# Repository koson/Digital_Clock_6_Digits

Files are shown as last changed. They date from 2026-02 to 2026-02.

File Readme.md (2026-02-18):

# Digital Clock 6 Digits

## คำแนะนำ
สร้างนาฬิกา Digital 6 Digit โดยใช้อุปกรณ์ที่เรียนในวิชา เพื่อแสดงเวลาในรูปแบบ HH:MM:SS โดยใช้หลักการทำงานของวงจร Digital Logic และ Counter 

โครงงานนี้ใช้วิธีการเดินสายด้วย Wire wrapping เพื่อลดขั้นตอนในการทำ PCB และเป็นการฝึกให้นักศึกษาได้บัดกรีวงจรที่มีความซับซ้อนในระดับที่เหมาะสม

รูปตัวอย่างของบอร์ดทั้งหมด ไม่ได้เป็นข้อบังคับให้นักศึกษาต้องทำให้เหมือน อีกทั้งนักศึกษาสามารถเพิ่มเติมฟังก์ชันที่ดีกว่าต้นฉบับได้ แต่ไม่ควรน้อยกว่าเป็นอันขาด

ไฟล์ทั้งหมดที่ใช้อธิบายการทำงานและสร้างโครงงาน อยู่ในโฟลเดอร์ Documents

#### ถ้ามีข้อสงสัยหรือต้องการคำอธิบายเพิ่ม ให้เปิด issue มาได้เลยนะครับ

## 🆘 ขี้เกียจอ่านยาว ๆ  เชิญทางนี้เลยครับ [🛝](./Documents/Short-Docs.md) 

## 🆘 หรือไม่อยากอ่านเลย อยากดูคลิปอย่างเดียว  ก็เชิญทางนี้เลยครับ [🎞️](./Documents/Video-Links.md) 

---

## 📐 สถาปัตยกรรม Hardware แบบ MVC (Model-View-Controller)

<p align="center">
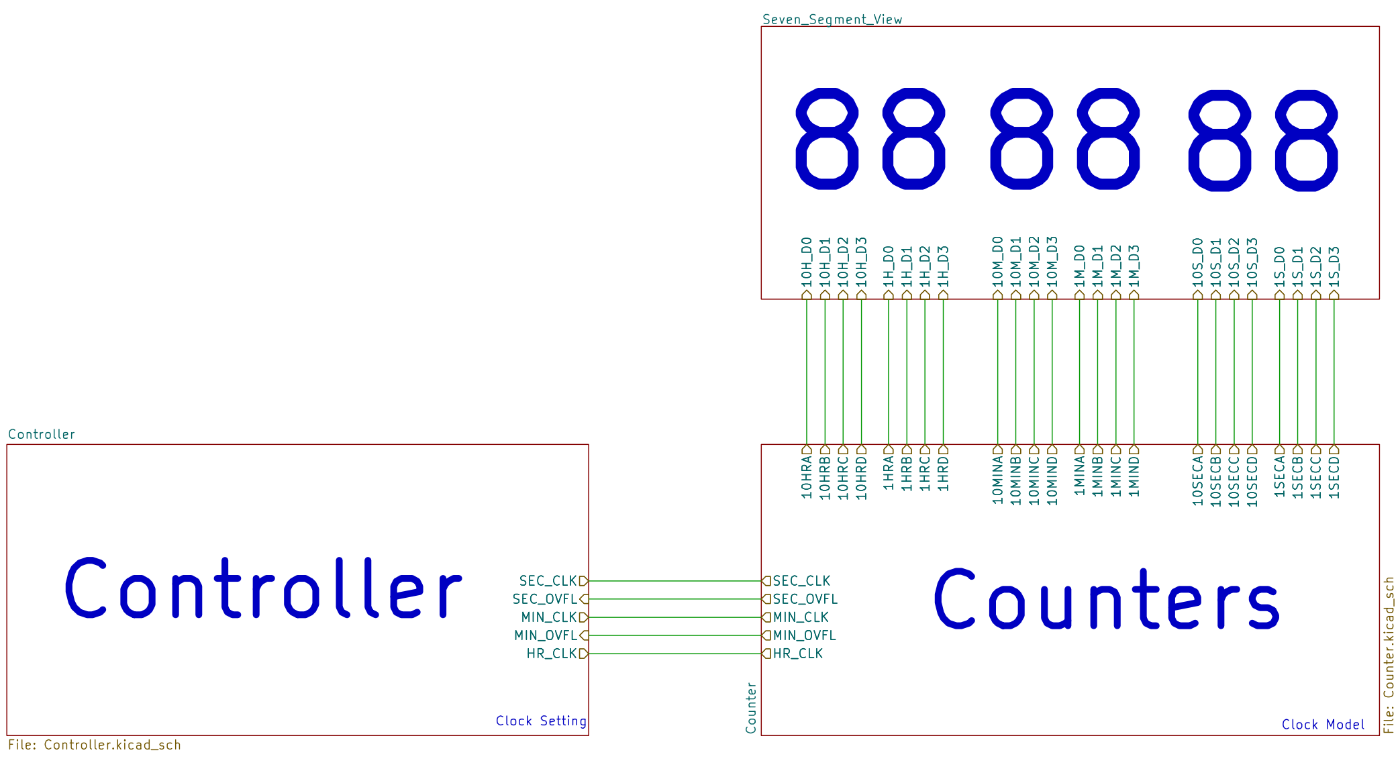
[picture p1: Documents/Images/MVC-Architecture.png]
MVC Architecture

</p>
โปรเจคนี้ออกแบบโดยแบ่งส่วนการทำงานออกเป็น 3 ส่วนหลักตามแนวคิด MVC:

### 🎮 **Controller** - ส่วนควบคุมและสร้างสัญญาณ Clock
- **หน้าที่:** สร้างสัญญาณนาฬิกา (Clock Signal) ที่ความถี่ 1 Hz (1 วินาที/รอบ) พร้อมทั้งสวิตช์กดเพื่อการตั้งเวลา
- **อุปกรณ์หลักส่วนกำเนิดสัญญาณนาฬิกา:** 
  - NE555 Timer ในโหมด Astable เพื่อสร้าง Clock pulse
  - LED และตัวต้านทาน  
- **ผลลัพธ์:** สัญญาณ Clock ที่มีความแม่นยำสำหรับนับเวลา สามารถสังเกตุการทำงานจากการกระพริบของ LED

- **อุปกรณ์หลักส่วนตั้งเวลาสำหรับนาฬิกา:** 
  - สวิตช์กด push button ชนิด กดติดปล่อยดับ
  - ตัวต้านทาน  Pull-up หรือ Pull Down
  - ตัวเก็บประจุ debouncing
  - SN7414 Schmitt Trigger สำหรับปรับสัญญาณให้เสถียร
  - SN7474 D Flip-Flop สำหรับสลับโหมด (RUN/SETTIME)
  - SN74LS157 Multiplexer สำหรับเลือกเส้นทางสัญญาณสำหรับโหมด  RUN และ SETTIME
- **ผลลัพธ์:** การกดปุ่มแต่ละครั้ง ไม่มี bounce และสามารถเปลี่ยนโหมด (RUN/SETTIME) และเพิ่มค่าในหลัก HH:MM:SS ครั้งละ 1 ได้ตามต้องการ 

### 📊 **Model** - ส่วนประมวลผลและนับเวลา (Counters)
- **หน้าที่:** นับและจัดเก็บค่าเวลา (ชั่วโมง นาที วินาที) ในรูปแบบ BCD
- **อุปกรณ์หลัก:**
  - SN74LS390 Decade Counter (นับเลข 0-9 และ 0-5)
- **โครงสร้างการนับ:**
  - วินาทีหลักหน่วย: 0-9 (ใช้ Counter mod-10)
  - วินาทีหลักสิบ: 0-5 (ใช้ Counter mod-6)
  - นาทีหลักหน่วย: 0-9 (ใช้ Counter mod-10)
  - นาทีหลักสิบ: 0-5 (ใช้ Counter mod-6)
  - ชั่วโมงหลักหน่วย: 0-9 (ใช้ Counter mod-10)
  - ชั่วโมงหลักสิบ: 0-2 (ใช้ Counter mod-3 สำหรับรูปแบบ 24 ชั่วโมง)

### 🖥️ **View** - ส่วนแสดงผล (7 Segments)
- **หน้าที่:** แสดงค่าเวลาออกทาง 7-Segment Display
- **อุปกรณ์หลัก:**
  - CD4543 BCD-to-7-Segment Decoder (6 ตัว สำหรับแต่ละหลัก)
  - 7-Segment Display Common Cathode (6 หลัก)
- **การทำงาน:** รับค่า BCD จาก Model แปลงเป็นรหัส 7-Segment เพื่อแสดงผลตัวเลข 0-9

---

## 🔧 การทำงานของแต่ละส่วนในโปรเจค

### 1. ส่วน Clock Generator (NE555)
- สร้างสัญญาณสี่เหลี่ยมความถี่ ~1 Hz
- ใช้สูตรคำนวณ: $f = \frac{1.44}{(R_1 + 2R_2) \times C}$
- ค่าที่ใช้: R1 = 1kΩ, R2 = 6.8kΩ, C = 100µF
- ความถี่ที่ได้: 0.986 Hz (ความคลาดเคลื่อน 1.4%)

### 2. ส่วน Counter (SN74LS390)
**วินาที:**
- Counter ตัวที่ 1: นับหลักหน่วย 0→9 (mod-10)
- Counter ตัวที่ 2: นับหลักสิบ 0→5 (mod-6)
- เมื่อครบ 59 วินาที Reset และส่งสัญญาณ Carry ไปยังส่วนนาที

**นาที:**
- Counter ตัวที่ 3: นับหลักหน่วย 0→9 (mod-10)
- Counter ตัวที่ 4: นับหลักสิบ 0→5 (mod-6)
- เมื่อครบ 59 นาที Reset และส่งสัญญาณ Carry ไปยังส่วนชั่วโมง

**ชั่วโมง:**
- Counter ตัวที่ 5: นับหลักหน่วย 0→9 (mod-10)
- Counter ตัวที่ 6: นับหลักสิบ 0→2 (mod-3)
- เมื่อครบ 23:59:59 Reset กลับเป็น 00:00:00

### 3. ส่วน Display (CD4543 + 7-Segment)
- รับสัญญาณ BCD 4 บิตจาก Counter แต่ละหลัก
- CD4543 ทำหน้าที่แปลง BCD เป็นสัญญาณควบคุม 7-Segment (a-g)
- แสดงผลตัวเลข 0-9 บน 7-Segment Display

### 4. ส่วน Time Setting
- Switch สำหรับหยุดนับและปรับเวลา
- Push Button สำหรับตั้งค่าชั่วโมง/นาที/วินาที

---

## 📁 คำอธิบายไฟล์ในโปรเจค

### 📄 Markdown Documents
- **`Readme.md`** - เอกสารหลักของโปรเจค อธิบายภาพรวมและวิธีการทำงาน
- **[`Bill-of-materials.md`](Documents/Bill-of-materials.md)** - รายการอุปกรณ์ที่ใช้ในโปรเจค
- **[`Construction-Process.md`](Construction-Process-Display.md)** - ขั้นตอนการประกอบวงจรตามลำดับ
- **[`Datasheets.md`](Documents/Datasheets.md)** - รายละเอียด Datasheet ของ IC ที่ใช้ในวงจร
- **[`Kicad-Setup.md`](Documents/Kicad-Setup.md)** - คู่มือการตั้งค่าและใช้งาน KiCad
- **[`NE555_Clock.md`](NE555-Clock-Generator.md)** - การคำนวณและออกแบบวงจร NE555

### 🔌 Circuit Files (โฟลเดอร์ Circuit/)
- **[`Digital_Clock_6_Digits.kicad_pro`](Circuit/Digital_Clock_6_Digits.kicad_pro)** - ไฟล์โปรเจค KiCad หลัก
- **[`Digital_Clock_6_Digits.kicad_sch`](Circuit/Digital_Clock_6_Digits.kicad_sch)** - Schematic หลักที่เชื่อมโยงส่วนย่อย
- **[`Controller.kicad_sch`](Circuit/Controller.kicad_sch)** - วงจร NE555 Clock Generator
- **[`Counter.kicad_sch`](Circuit/Counter.kicad_sch)** - วงจร Counter ทุกหลัก (วินาที นาที ชั่วโมง)
- **[`7Seg_6Digits.kicad_sch`](Circuit/7Seg_6Digits.kicad_sch)** - วงจร Decoder และ Display 6 หลัก
- **[`Seven_Segment_View.kicad_sch`](Circuit/Seven_Segment_View.kicad_sch)** - มุมมองการเชื่อมต่อ 7-Segment
- **[`Digital_Clock_6_Digits.kicad_pcb`](Circuit/Digital_Clock_6_Digits.kicad_pcb)** - ไฟล์ออกแบบ PCB
- **[`Library.kicad_sym`](Circuit/Library.kicad_sym)** - ไลบรารีสัญลักษณ์ที่ใช้ในโปรเจค
- **[`Digital_Clock_6_Digits.csv`](Circuit/Digital_Clock_6_Digits.csv)** - Bill of Materials จาก KiCad

---

## 🛠️ ลำดับขั้นตอนการทำโปรเจค

``` mermaid
%%{init: {'theme':'base', 'flowchart': {'padding': 20, 'nodeSpacing': 50, 'rankSpacing': 50}, 'themeVariables': {'fontSize':'13px', 'fontFamily':'Arial'}}}%%
flowchart TD
    Phase1["Study documentation"] --> Phase2["Study schematic in Kicad"]
    Phase2 --> Phase3["Acquire components"]   

    subgraph "building circuit"
        direction TB
        Phase4
        Phase5
        Phase6
    end
    Phase3 --> Phase4["Build Display circuit"]
    Phase4 --> Phase5["Build Counter circuit"]
    Phase5 --> Phase6["Build Controller circuit"]
    Phase6 --> Phase7["Test and Debug"]
    Phase7 --> Phase7-1{"Does it work?"}
    Phase7-1 -->|Yes| Phase8["Document and Publish"]
    Phase7-1 -->|No| Phase3["Acquire components"]
```

### Phase 1: ศึกษาเอกสารต่างๆ (เริ่มจากไฟล์ Readme.md)
- [ ] **ศึกษา Datasheet** ของ IC แต่ละตัวให้เข้าใจการทำงาน โดยเฉพาะ:
	- [ ] CD4543 (BCD-to-7-Segment Decoder)
	- [ ] SN74LS390 (Decade Counter)
	- [ ] NE555 (Timer)
	- [ ] SN74LS157 (Multiplexer)

- [ ] **ศึกษาวงจรย่อย** แต่ละส่วนที่อาจารย์ให้ไว้:
	- [ ] วงจร Clock Generator (NE555)
	- [ ] วงจร Counter (SN74LS390) สำหรับ วินาที นาที ชั่วโมง
    - [ ] วงจร Display (CD4543 + 7-Segment)

- [ ]  **คำนวณค่าอุปกรณ์:** ถ้าอุปกรณ์ที่หามาได้ไม่ตรงกับค่าในวงจร 
	- [ ]  คำนวณ R และ C สำหรับ NE555 ให้ได้ความถี่ 1 Hz
	- [ ]  ตรวจสอบ Duty Cycle ให้อยู่ในช่วง 40-60%

### Phase 2: ศึกษาวงจรใน KiCad (ต้องลงโปรแกรม KiCad)
- [ ] **สร้าง Schematic แยกตามส่วน:**
    - [ ] `Controller.kicad_sch` - วงจร NE555
    - [ ] `Counter.kicad_sch` - วงจรนับเวลา
    - [ ] `7Seg_6Digits.kicad_sch` - วงจรแสดงผล
    - [ ] `Digital_Clock_6_Digits.kicad_sch` - เชื่อมโยงทุกส่วนเข้าด้วยกัน

- [ ] **ตรวจสอบความถูกต้อง:**
    - [ ] ตรวจสอบการเชื่อมต่อระหว่างส่วน
    - [ ] ตรวจสอบ Power Supply (VCC, GND)
    - [ ] ใช้มัลติมิเตอร์ตรวจสอบข้อผิดพลาด

### Phase 3: จัดหาอุปกรณ์ตามรายการ
- [ ] **จัดทำรายการอุปกรณ์ (BOM - Bill of Materials):**
    - [ ] IC ทั้งหมดตาม Schematic (CD4543, SN74LS390, NE555, SN74LS157, SN7414, SN7474)
    - [ ] 7-Segment Display Common Cathode 6 หลัก ควรใส่ Socket หรือ connector ตามคำแนะนำในการประกอบวงจร
    - [ ] ตัวต้านทาน (Resistor) ค่าต่างๆ ตามที่คำนวณไว้ในวงจร
    - [ ] ตัวเก็บประจุ (Capacitor) สำหรับวงจร NE555 และ Decoupling
    - [ ] แผ่นวงจรเอนกประสงค์ (Universal PCB) ขนาดที่เหมาะสม
    - [ ] IC Socket สำหรับ IC ทุกตัว (แนะนำให้ใช้เพื่อความสะดวกในการเปลี่ยน IC)
    - [ ] สาย Wire Wrap หรือสายเดินสายแบบอ่อน (Jumper Wire)
    - [ ] Push Button Switch สำหรับตั้งค่าเวลา
    - [ ] LED สำหรับแสดงสถานะ Clock
    - [ ] แหล่งจ่ายไฟ 5V (Adapter หรือ Battery)

- [ ] **ตรวจสอบอุปกรณ์:**
    - [ ] ตรวจสอบความถูกต้องของ IC ทุกตัวด้วย Datasheet
    - [ ] ทดสอบค่าตัวต้านทานและตัวเก็บประจุด้วย Multimeter
    - [ ] ตรวจสอบ 7-Segment Display ว่าเป็น Common Cathode
    - [ ] เตรียมอุปกรณ์สำรอง (IC, ตัวต้านทาน, สาย) กรณีชำรุด

### Phase 4: ประกอบส่วน Display
- [ ] **เตรียมอุปกรณ์สำหรับส่วน Display:**
    - [ ] IC Socket สำหรับ CD4543 (6 ตัว)
    - [ ] CD4543 BCD-to-7-Segment Decoder (6 ตัว)
    - [ ] 7-Segment Display Common Cathode (6 หลัก)
    - [ ] ตัวต้านทาน Current Limiting สำหรับ LED แต่ละ Segment
    - [ ] แผ่นวงจรเอนกประสงค์ขนาดพอเหมาะ

- [ ] **วางตำแหน่ง Component:**
    - [ ] วาง 7-Segment Display ให้เรียงตามลำดับ (HH:MM:SS)
    - [ ] วาง IC Socket สำหรับ CD4543 ไว้ใกล้กับ 7-Segment แต่ละหลัก
    - [ ] วางตำแหน่งให้พิจารณาเส้นทางการเดินสายไปยัง Counter (ส่วนถัดไป)
    - [ ] สามารถวางตามตัวอย่างในรูปชิ้นงานที่สำเร็จแล้วได้ 

- [ ] **บัดกรี Component:**
    - [ ] บัดกรี 7-Segment Display ทั้ง 6 หลัก ตรวจสอบให้แน่ใจว่าหลักตรง
    - [ ] บัดกรี IC Socket สำหรับ CD4543 ทั้ง 6 ตัว ตรวจสอบทิศทางขา 1
    - [ ] บัดกรีตัวต้านทาน Current Limiting สำหรับแต่ละ Segment

- [ ] **เดินสายด้วย Wire Wrap:**
    - [ ] เชื่อมต่อสาย VCC และ GND ให้ทุก IC (ควรเดินสายเป็นแนว Bus)
    - [ ] เชื่อมต่อสาย Output a-g จาก CD4543 ไปยัง 7-Segment แต่ละหลัก
    - [ ] เชื่อมต่อขา Common Cathode ของ 7-Segment ทั้งหมดไปยัง GND
    - [ ] เตรียมจุดต่อสำหรับสาย Input BCD (4 บิต) จากส่วน Counter

- [ ] **ทดสอบส่วน Display:**
    - [ ] **ยังไม่ต้องใส่ CD4543 ลงใน IC Socket**
    - [ ] จ่ายไฟ 5V ตรวจสอบแรงดันที่ขาไฟเลี้ยงและ ground ของ IC ทุกตัว
    - [ ] ถ้าวัดไฟแล้วไม่มีอะไรผิดพลาด ให้ปลดไฟเลี้ยงออกแล้วเสียบ IC ลงไปใน socket โดยทำจากหลักวินาทีเพียงตัวเดียวก่อน
    - [ ] จ่ายไฟเข้าวงจร IC ต้องไม่ร้อนกว่าปกติ วัดแรงดันไฟเลี้ยงควรได้เท่ากับตอนที่ยังไม่เสียบ IC 
    - [ ] ทดสอบการแสดงผลด้วยการจ่ายสัญญาณ BCD แบบ Manual (ใช้สวิตช์หรือสาย Jumper)
    - [ ] ตรวจสอบว่าแต่ละหลักสามารถแสดงตัวเลข 0-9 ได้ถูกต้อง
    - [ ] บันทึกปัญหาที่พบ (ถ้ามี) เช่น Segment ที่ไม่ติด

### Phase 5: ประกอบส่วน Counter
- [ ] **เตรียมอุปกรณ์สำหรับส่วน Counter:**
    - [ ] IC Socket สำหรับ SN74LS390 (3 ตัว สำหรับ วินาที นาที ชั่วโมง)
    - [ ] SN74LS390 Dual Decade Counter (3 ตัว)
    - [ ] ตัวเก็บประจุ Decoupling 0.1µF สำหรับแต่ละ IC
    - [ ] แผ่นวงจรเอนกประสงค์ขนาดพอเหมาะ (หรือใช้แผ่นเดียวกับ Display)

- [ ] **วางตำแหน่ง Component:**
    - [ ] วาง IC Socket สำหรับ Counter ตามลำดับ: วินาที → นาที → ชั่วโมง
    - [ ] วางให้สะดวกต่อการเชื่อมต่อกับส่วน Display และ Controller
    - [ ] คำนึงถึงการเดินสายระหว่าง Counter แต่ละหลัก (Cascade)
    - [ ] สามารถวางตำแหน่งตามในรูปวงจรต้นแบบได้

- [ ] **บัดกรี Component:**
    - [ ] บัดกรี IC Socket สำหรับ SN74LS390 ทั้ง 3 ตัว
    - [ ] บัดกรีตัวเก็บประจุ Decoupling ไว้ใกล้ขา VCC และ GND ของแต่ละ IC
    - [ ] บัดกรี IC Logic Gate เพิ่มเติม (ถ้ามี) สำหรับวงจร Reset

- [ ] **เดินสายด้วย Wire Wrap:**
    - [ ] เชื่อมต่อสาย VCC และ GND ให้ทุก IC
    - [ ] **วงจรวินาที:** บัดกรีวงจรตามที่แสดงใน Kicad
        - [ ] เชื่อมต่อ Clock Input สำหรับนับวินาทีหลักหน่วย (0-9)
        - [ ] เชื่อมต่อ Carry Output ไปยังหลักสิบ (0-5)
        - [ ] ต่อขา Output BCD (4 บิต) ของทั้ง 2 หลักไปยังส่วน Display
        - [ ] ต่อวงจร Reset เมื่อครบ 59 → 00
    - [ ] **วงจรนาที:** บัดกรีวงจรตามที่แสดงใน Kicad
        - [ ] รับ Clock Input จาก Carry ของวินาทีหลักสิบ
        - [ ] เชื่อมต่อ Carry Output ไปยังหลักสิบ (0-5)
        - [ ] ต่อขา Output BCD ไปยังส่วน Display
        - [ ] ต่อวงจร Reset เมื่อครบ 59 → 00
    - [ ] **วงจรชั่วโมง:** บัดกรีวงจรตามที่แสดงใน Kicad
        - [ ] รับ Clock Input จาก Carry ของนาทีหลักสิบ
        - [ ] เชื่อมต่อหลักหน่วย (0-9) และหลักสิบ (0-2)
        - [ ] ต่อขา Output BCD ไปยังส่วน Display
        - [ ] ต่อวงจร Reset เมื่อครบ 23 → 00 (รูปแบบ 24 ชั่วโมง)

- [ ] **เชื่อมต่อส่วน Display เข้ากับ Connector ทั้ง 6 ตัว:**
    - [ ] ต่อสาย BCD Output จาก Counter แต่ละหลักไปยัง Input ของ CD4543
    - [ ] ตรวจสอบความถูกต้องของการต่อสาย (bit 0-3)

- [ ] **ทดสอบส่วน Counter:**
    - [ ] ใส่ IC SN74LS390 ลงใน IC Socket ทุกตัว
    - [ ] จ่ายไฟ 5V และตรวจสอบแรงดันที่ IC ทุกตัว
    - [ ] จ่ายสัญญาณ Clock แบบ Manual (กดปุ่มหรือใช้ Switch)
    - [ ] ตรวจสอบการนับของวินาที: 00 → 01 → ... → 09 → 10 → ... → 59 → 00
    - [ ] ตรวจสอบ Carry Signal ส่งต่อไปยังนาทีเมื่อวินาทีครบ 59
    - [ ] ตรวจสอบการนับของนาทีและชั่วโมงแบบเดียวกัน
    - [ ] ตรวจสอบว่าเมื่อครบ 23:59:59 แล้ว จะ Reset เป็น 00:00:00

### Phase 6: ประกอบส่วน Controller (Clock Generator และ Time Setting)
- [ ] **เตรียมอุปกรณ์สำหรับส่วน Controller:**
    - [ ] IC Socket สำหรับ NE555, SN7414, SN7474, SN74LS157
    - [ ] NE555 Timer IC
    - [ ] SN7414 Schmitt Trigger (สำหรับปรับสัญญาณ)
    - [ ] SN7474 D Flip-Flop (สำหรับสลับโหมด RUN/SETTIME)
    - [ ] SN74LS157 Multiplexer (สำหรับเลือกสัญญาณ Clock)
    - [ ] ตัวต้านทาน 1kΩ, 6.8kΩ (หรือค่าที่คำนวณได้)
    - [ ] ตัวเก็บประจุ 100µF (หรือค่าที่คำนวณได้)
    - [ ] Push Button Switch (สำหรับ Mode Switch, Hour, Minute, Second)
    - [ ] LED สำหรับแสดงสถานะ Clock และโหมด
    - [ ] ตัวต้านทาน Pull-up/Pull-down สำหรับปุ่ม
    - [ ] ตัวเก็บประจุ Debouncing สำหรับปุ่มกด
    - [ ] แผ่นวงจรเอนกประสงค์ขนาดพอเหมาะ

- [ ] **ส่วน Clock Generator (NE555):**
    - [ ] บัดกรี IC Socket สำหรับ NE555
    - [ ] บัดกรีตัวต้านทาน R1 (1kΩ) และ R2 (6.8kΩ)
    - [ ] บัดกรีตัวเก็บประจุ C (100µF)
    - [ ] บัดกรี LED และตัวต้านทาน Current Limiting
    - [ ] เดินสายตาม Schematic ของ NE555 Astable Mode
    - [ ] เชื่อม Output ของ NE555 ไปยัง SN7414 (Schmitt Trigger)

- [ ] **ส่วน Time Setting:**
    - [ ] บัดกรี Push Button ทั้งหมด (Mode, Hour, Minute, Second)
    - [ ] บัดกรีตัวต้านทาน Pull-up/Pull-down สำหรับปุ่มแต่ละตัว
    - [ ] บัดกรีตัวเก็บประจุ Debouncing ควบคู่กับปุ่ม
    - [ ] บัดกรี IC Socket สำหรับ SN7414, SN7474, SN74LS157
    - [ ] เดินสาย Output จากปุ่มผ่าน SN7414 เพื่อปรับสัญญาณให้เสถียร
    - [ ] เดินสายจาก SN7474 เพื่อสลับระหว่างโหมด RUN และ SETTIME
    - [ ] เดินสายจาก SN74LS157 เพื่อเลือก Clock Source:
        - [ ] โหมด RUN: ใช้สัญญาณจาก NE555 (1 Hz)
        - [ ] โหมด SETTIME: ใช้สัญญาณจากปุ่มกด (Manual Clock)

- [ ] **เชื่อมต่อกับส่วน Counter:**
    - [ ] ต่อ Output จาก Multiplexer (SN74LS157) ไปยัง Clock Input ของ Counter
    - [ ] ต่อสัญญาณจากปุ่ม Hour, Minute, Second ไปยัง Clock Input ของ Counter ที่เกี่ยวข้อง (ผ่าน Multiplexer)

- [ ] **ทดสอบส่วน Controller:**
    - [ ] **ทดสอบ NE555 Clock Generator:**
        - [ ] จ่ายไฟ 5V และสังเกตการกระพริบของ LED
        - [ ] ถ้าสามารถ ให้วัดความถี่ด้วย Oscilloscope หรือ Frequency Counter (ควรได้ ~1 Hz)
        - [ ] ถ้าสามารถ ให้วัด Duty Cycle ควรอยู่ในช่วง 40-60%
    - [ ] **ทดสอบ Push Button และ Debouncing:**
        - [ ] กดปุ่มแต่ละตัวและตรวจสอบว่าไม่มี Bounce (อาจจะใช้ Oscilloscope หรือ Logic Probe แต่จากการออกแบบวงจร ไม่ควรจะเกิด bounce ถ้าบัดกรีถูกต้อง)
        - [ ] ตรวจสอบว่า Schmitt Trigger ทำงานถูกต้อง
    - [ ] **ทดสอบ Mode Switch (RUN/SETTIME):**
        - [ ] กดปุ่ม Mode และตรวจสอบว่า D Flip-Flop สลับสถานะ
        - [ ] ตรวจสอบว่า LED แสดงโหมดปัจจุบัน (RUN หรือ SETTIME)
    - [ ] **ทดสอบ Multiplexer:**
        - [ ] ในโหมด RUN: Counter ต้องนับตามสัญญาณจาก NE555 (1 วินาที/ครั้ง)
        - [ ] ในโหมด SETTIME: การกดปุ่ม Hour/Minute/Second ต้องเพิ่มค่าในหลักที่ถูกต้อง

### Phase 7: การทดสอบและแก้ไขปัญหา (Testing & Debugging)
- [ ] **ทดสอบการทำงานของแต่ละส่วนร่วมกัน:**
    - [ ] เชื่อมต่อทุกส่วนเข้าด้วยกัน: Controller → Counter → Display
    - [ ] จ่ายไฟ 5V และตรวจสอบแรงดันที่ IC ทุกตัว (ควรได้ 4.75-5.25V)
    - [ ] สังเกตการแสดงผลบน 7-Segment Display

- [ ] **ทดสอบโหมด RUN (การทำงานปกติ):**
    - [ ] ตั้งเวลาเริ่มต้นเป็น 00:00:00
    - [ ] สังเกตการนับวินาที ควรเพิ่มทีละ 1 ทุกวินาที
    - [ ] ตรวจสอบการ Carry: 00:00:59 → 00:01:00, 00:59:59 → 01:00:00
    - [ ] ทดสอบการ Reset เมื่อครบ 23:59:59 → 00:00:00
    - [ ] ให้วงจรทำงานต่อเนื่อง 1-2 ชั่วโมง เพื่อตรวจสอบความเสถียร

- [ ] **ทดสอบโหมด SETTIME (การตั้งเวลา):**
    - [ ] กดปุ่ม Mode เพื่อเข้าสู่โหมด SETTIME
    - [ ] กดปุ่ม Hour และตรวจสอบว่าชั่วโมงเพิ่มขึ้น
    - [ ] กดปุ่ม Minute และตรวจสอบว่านาทีเพิ่มขึ้น
    - [ ] กดปุ่ม Second และตรวจสอบว่าวินาทีเพิ่มขึ้น
    - [ ] กดปุ่ม Mode อีกครั้งเพื่อกลับสู่โหมด RUN
    - [ ] ตรวจสอบว่านาฬิกานับต่อจากเวลาที่ตั้งไว้

- [ ] **ทดสอบความแม่นยำของเวลา:**
    - [ ] เปรียบเทียบกับนาฬิกามาตรฐาน (นาฬิกาข้อมือ, โทรศัพท์)
    - [ ] ให้วงจรทำงานต่อเนื่อง 24 ชั่วโมง
    - [ ] วัดความคลาดเคลื่อนของเวลา (ควรไม่เกิน ±1-2 นาที/วัน)
    - [ ] หากความคลาดเคลื่อนมาก ให้ปรับค่า R หรือ C ของ NE555

- [ ] **การแก้ไขปัญหาทั่วไป:**
    - [ ] **Display ไม่แสดงผล:**
        - [ ] ตรวจสอบการต่อขา IC และ 7-Segment
        - [ ] ตรวจวัดแรงดันที่ขา VCC และ GND
        - [ ] ตรวจสอบตัวต้านทาน Current Limiting
    - [ ] **Counter นับไม่ถูกต้อง:**
        - [ ] ตรวจสอบสัญญาณ Clock ด้วย Oscilloscope หรือ Logic Probe
        - [ ] ตรวจสอบวงจร Reset (อาจ Reset บ่อยเกินไปหรือไม่ Reset)
        - [ ] ตรวจสอบการต่อ Carry Signal ระหว่าง Counter
    - [ ] **Clock ความถี่ไม่ถูกต้อง:**
        - [ ] วัดค่าจริงของ R และ C ด้วย Multimeter
        - [ ] คำนวณความถี่ใหม่และปรับค่า R หรือ C
        - [ ] ตรวจสอบการต่อวงจร NE555
    - [ ] **ปุ่มกดมี Bounce:**
        - [ ] เพิ่มตัวเก็บประจุ Debouncing (0.1-1µF)
        - [ ] ตรวจสอบวงจร Schmitt Trigger
    - [ ] **นาฬิกาหยุดทำงานหลังทำงานได้สักพัก:**
        - [ ] ตรวจสอบการบัดกรีที่หลวม (Cold Solder Joint)
        - [ ] ตรวจสอบแหล่งจ่ายไฟว่ามีกระแส (Current) เพียงพอ
        - [ ] เพิ่มตัวเก็บประจุ Decoupling ที่ IC ทุกตัว

### Phase 8: เอกสารและการสรุปผล (Documentation)
- [ ] **ถ่ายภาพและวิดีโอ:**
    - [ ] ถ่ายภาพวงจรที่ประกอบเสร็จจากหลายมุม
    - [ ] ถ่ายภาพ Close-up ของแต่ละส่วนสำคัญ (Display, Counter, Controller)
    - [ ] ถ่ายภาพการเดินสายด้วย Wire Wrap
    - [ ] ถ่ายวิดีโอการทำงานของนาฬิกา ให้เห็นการเปลี่ยนวินาที 57 --> 58 --> 59 --> 00 --> 01 (อย่างน้อย 5 นาที) ทั้งในหลัก วินาที  --> นาที, นาที --> ชั่วโมง และเมื่อเปลี่ยน 23:59:xx ไปเป็น 00:00:xx
    - [ ] ถ่ายวิดีโอการตั้งเวลา (แสดงการใช้งานปุ่มกด)

- [ ] **บันทึกข้อมูลทางเทคนิค:**
    - [ ] รายการ IC ทั้งหมดที่ใช้พร้อมรุ่นและจำนวน
    - [ ] ค่าตัวต้านทานและตัวเก็บประจุที่ใช้จริง
    - [ ] ค่าความถี่ของ Clock ที่วัดได้
    - [ ] ความคลาดเคลื่อนของเวลาที่วัดได้
    - [ ] BOM (Bill of Materials) ฉบับสมบูรณ์

- [ ] **บันทึกปัญหาและวิธีแก้ไข:**
    - [ ] ปัญหาที่พบระหว่างการประกอบและทดสอบ
    - [ ] วิธีการแก้ไขปัญหาแต่ละอย่าง
    - [ ] ข้อผิดพลาดที่เกิดขึ้นและบทเรียนที่ได้รับ
    - [ ] คำแนะนำสำหรับผู้ที่จะทำโปรเจคนี้ต่อไป

- [ ] **เขียนเอกสารสรุป:**
    - [ ] วัตถุประสงค์ของโปรเจค
    - [ ] หลักการทำงานของนาฬิกา Digital
    - [ ] การออกแบบวงจรและการคำนวณ
    - [ ] ขั้นตอนการประกอบโดยสังเขป
    - [ ] ผลการทดสอบและประเมินความสำเร็จ
    - [ ] สรุปและข้อเสนอแนะ

- [ ] **เผยแพร่บน GitHub (ถ้าต้องการ):**
    - [ ] อัพโหลดไฟล์ Schematic (KiCad)
    - [ ] อัพโหลดรูปภาพ
    - [ ] อัพโหลดวิดีโอขึ้น YouTube และแปะลิ้งค์ไว้บน Github
    - [ ] อัพเดต README.md ให้มีข้อมูลครบถ้วน
    - [ ] เพิ่ม Bill of Materials (BOM)
    - [ ] เพิ่มคู่มือการประกอบ (Construction Process)
    - [ ] เขียน License และ Contributors
    - [ ] เปิดให้ผู้สนใจสามารถเปิด Issue หรือ Pull Request ได้

---

## 📚 เอกสารอ้างอิง
- [Bill of Materials](./Documents/Bill-of-materials.md) - รายการอุปกรณ์
- [Construction Process](./Documents/Construction-Process-Display.md) - ขั้นตอนการประกอบ
- [Datasheets](./Documents/Datasheets.md) - ข้อมูล IC ที่ใช้
- [NE555 Clock Calculation](./Documents/NE555-Clock-Generator.md) - การคำนวณวงจร Clock

---

## วงจรที่ประกอบสำเร็จแล้ว

<p align="center">
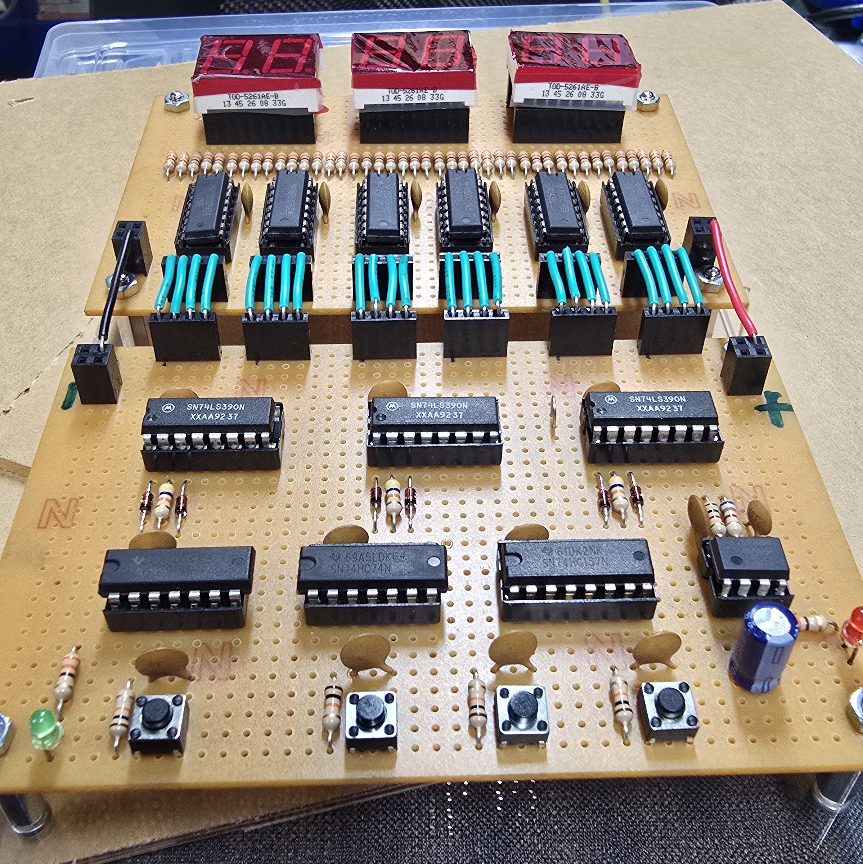
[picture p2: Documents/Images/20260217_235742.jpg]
Completed Circuit 1

</p>

<p align="center">
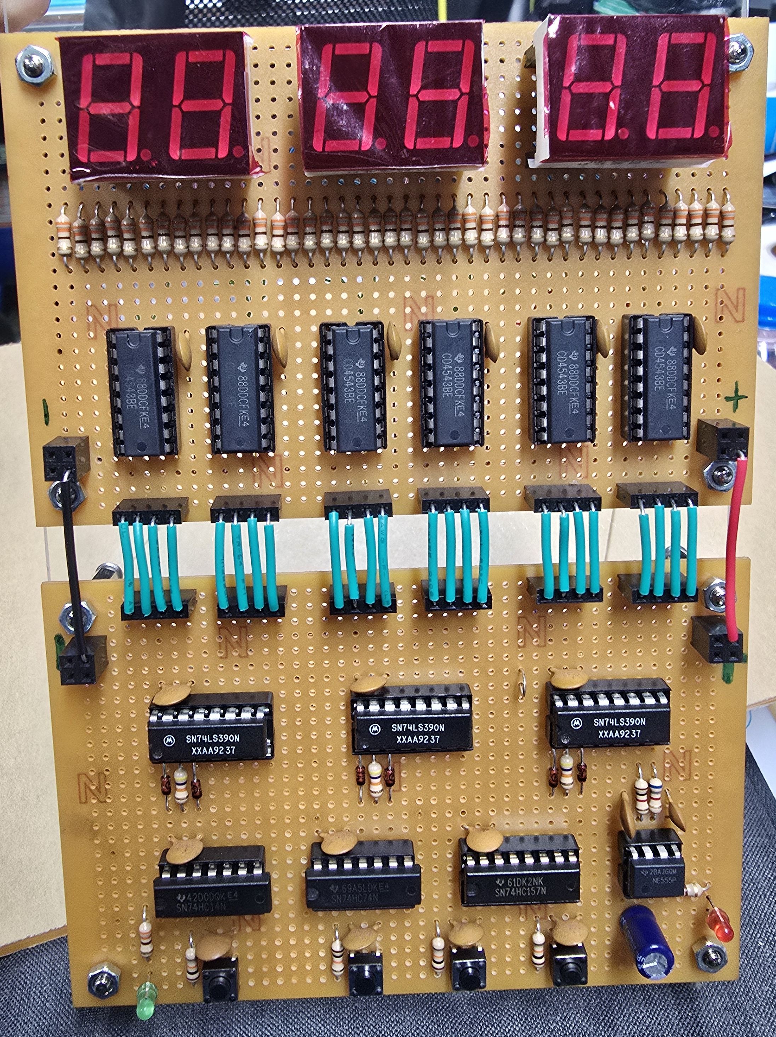
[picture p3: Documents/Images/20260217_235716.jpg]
Completed Circuit 2

</p>

<p align="center">
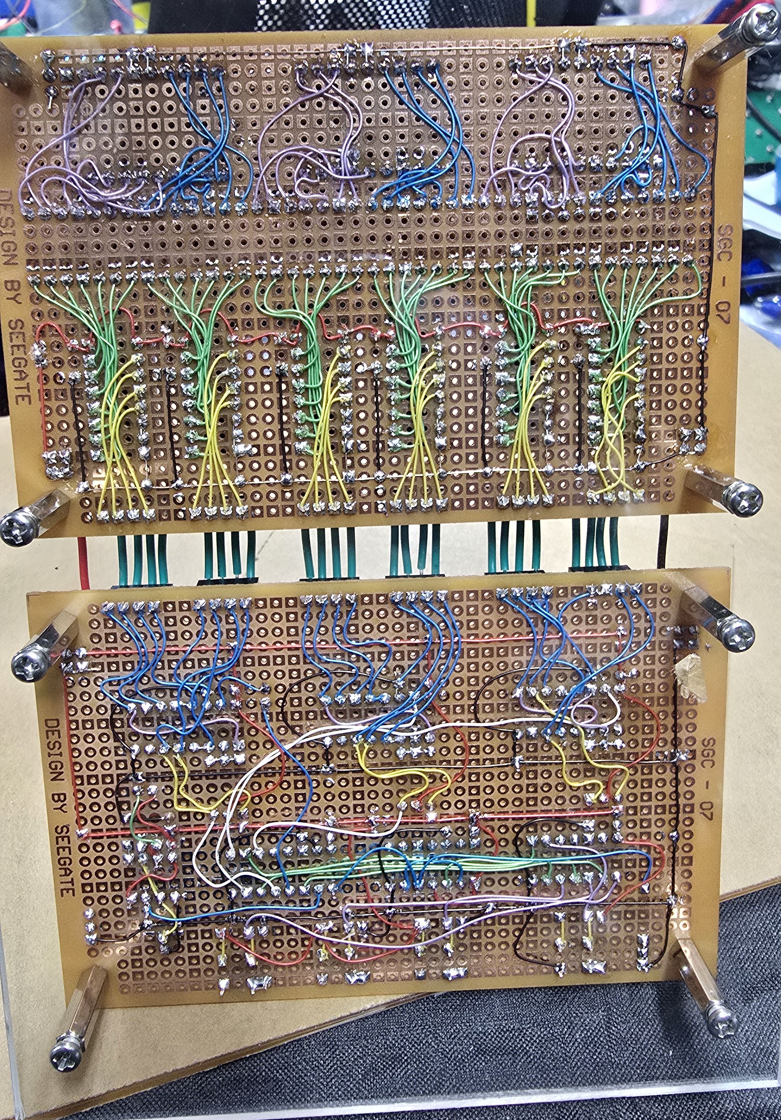
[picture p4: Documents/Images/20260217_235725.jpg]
Completed Circuit 3

</p>

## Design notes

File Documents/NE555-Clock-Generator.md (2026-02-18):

# NE555 Clock Generator

Circuit diagram for a 555 timer in astable mode, which can be used as a clock generator. The frequency of the clock can be adjusted by changing the values of the resistors and capacitor connected to the timer.

<p align="center">
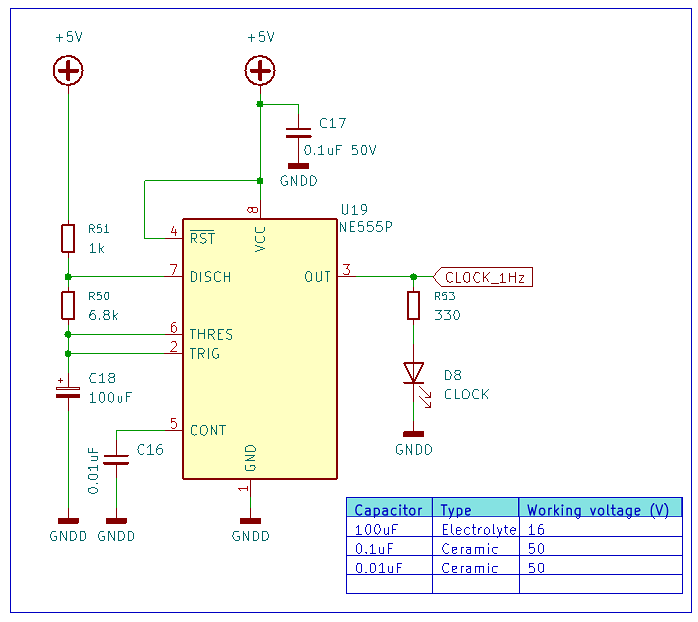
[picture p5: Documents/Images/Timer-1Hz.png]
NE555 Timer 1Hz

</p>

## Frequency calculation:
$$f = \frac{1.44}{(1k + 2 \times 6.8k) \times 100\mu F} = \frac{1.44}{14.6k \times 100\mu F} = \frac{1.44}{1.46} = 0.986 \text{ Hz}$$

### Error calculation: 

$$\frac{|1.0 - 0.986|}{1.0} \times 100\\% = 1.4\\%$$

#### **Result:** Acceptable for educational purposes. (within ±5%) 

## Duty Cycle calculation:
$$D = \frac{1k + 6.8k}{1k + 2 \times 6.8k}\times 100\\% = \frac{7.8k}{14.6k} \times 100\\% = 53.4\\%$$

#### **Result:** Okay. (within 40-60%)

## Period calculation:
$$T = \frac{1}{0.986} = 1.014 \text{ seconds}$$

High Time:
$$t_H = 0.693 \times (1k + 6.8k) \times 100\mu F = 0.693 \times 7.8k \times 100\mu F = 540.5 \text{ ms}$$

Low Time:
$$t_L = 0.693 \times 6.8k \times 100\mu F = 471.2 \text{ ms}$$

Check: 
$$t_H + t_L = 540.5 + 471.2 = 1011.7 \text{ms}  ≈ 1.01 s $$
#### **Result:** Acceptable. (within ±5%)

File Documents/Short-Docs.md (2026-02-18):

## ขั้นตอนการทำโครงงานนาฬิกา Digital Clock 6 Digits

### ขั้นที่ 1 ลงโปรแกรม Kicad ก่อนครับ เพื่อเปิดดูวงจร

คลิกที่นี่เพื่อดูวิธีการติดตั้งและใช้งาน Kicad ได้เลยครับ [การติดตั้งและใช้ KiCad เปิดดูวงจร](Kicad-Setup.md)

### ขั้นที่ 2 หาของเพื่อประกอบวงจร

คลิกเพื่อดู Bill of Materials (รายการอุปกรณ์) ที่เตรียมไว้ให้แล้วครับ [รายการอุปกรณ์](Bill-of-materials.md)

### ขั้นที่ 3 ประกอบวงจร Display ก่อน จะได้เห็นผลการนับ

คลิกเพื่อดูขั้นตอนการประกอบวงจรแสดงตัวเลข [ขั้นตอนการประกอบวงจร Display](Construction-Process-Display.md)

### ขั้นที่ 4 ประกอบวงจรนับ แล้วเอาไปต่อกับ Display

คลิกเพื่อดูขั้นตอนการประกอบวงจรนับเวลา [ขั้นตอนการประกอบวงจร Counter](Construction-Process-Counter.md)

### ขั้นที่ 5 ทำวงจรตั้งเวลา

คลิกเพื่อดูขั้นตอนการประกอบวงจรตั้งเวลา [ขั้นตอนการประกอบวงจร Time Setting](Construction-Process-Time-Setting.md)

### ขั้นที่ 6 ทดสอบ (แก้ไข ถ้ามีที่ผิด)

### ขั้นที่ 7 ส่ง พร้อม เอกสาร

### หมายเหตุ ในแต่ละขั้นให้ ถ่ายรูป อัดคลิป ไว้ด้วยนะครับ

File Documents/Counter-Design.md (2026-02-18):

# วงจรนับเวลา (Counter) 

### Counter 00-59 วินาที
<p align="center">
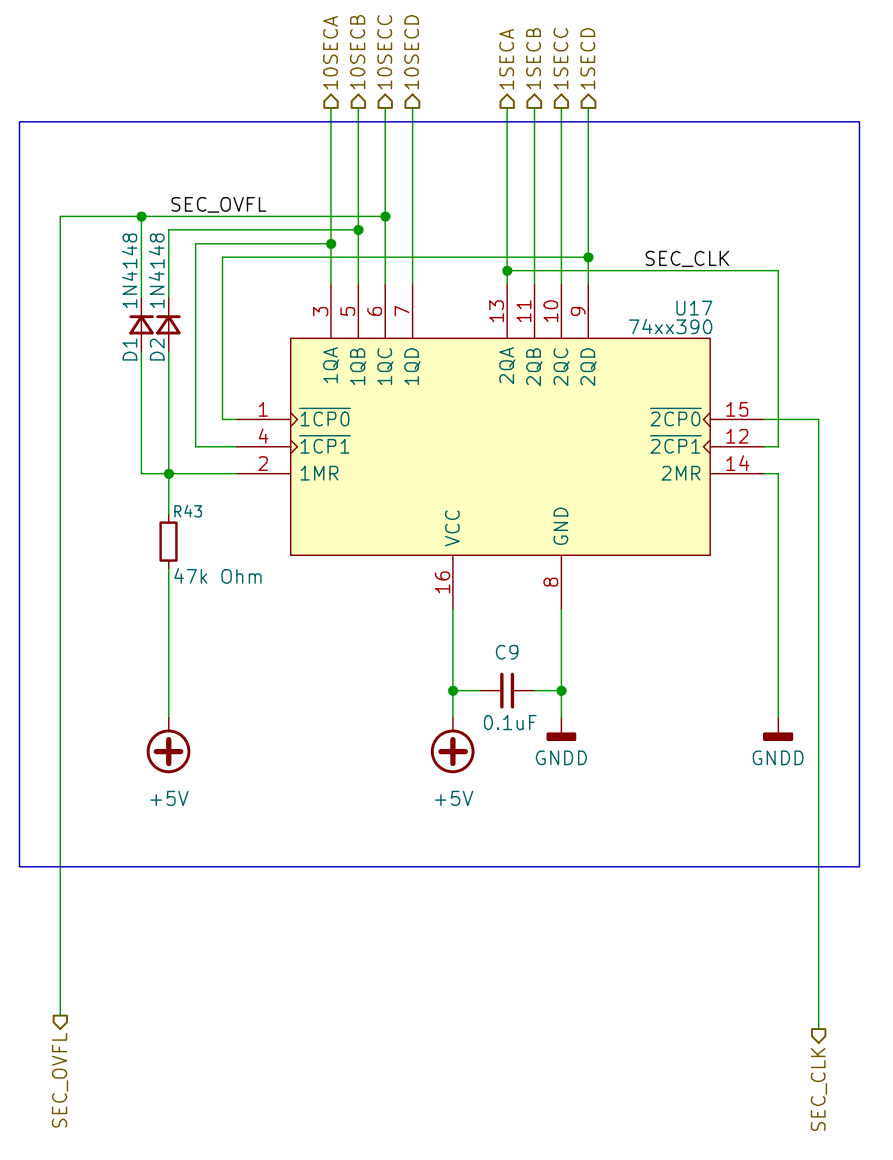
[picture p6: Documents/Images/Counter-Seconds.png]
Counter Seconds

<br> <b>รูปที่ 1 </b> วงจรนับวินาที
</p>

วงจรนี้ ประกอบด้วย Counter 2 ตัว โดยตัวแรกจะนับเลข 0-9 สำหรับหลักหน่วยวินาที และตัวที่สองจะนับเลข 0-5 สำหรับหลักสิบวินาที ซึ่งเมื่อรวมกันแล้วจะสามารถนับเวลาได้ตั้งแต่ 00 ถึง 59 วินาที

การนับ 0 - 9 เป็นพฤติกรรมปกติของ 74'390  ซึ่งเป็น Counter mod-10 ซึ่งจะรีเซ็ตกลับไปที่ 0 หลังจากนับถึง 9 และส่งสัญญาณ carry ไปยัง Counter ตัวถัดไปเพื่อเพิ่มค่าของหลักสิบวินาที

การนับ 0 - 5 สำหรับหลักสิบวินาที จะใช้ Counter mod-6 ซึ่งจะรีเซ็ตกลับไปที่ 0 หลังจากนับถึง 5 และส่งสัญญาณ carry ไปยัง Counter ตัวถัดไปเพื่อเพิ่มค่าของหลักนาที โดยอาศัยอุปกรณ์ภายนอก เช่น AND gate มาทำการรีเซ็ต Counter ตัวที่สองเมื่อมันนับถึง 6 เพื่อให้มันรีเซ็ตกลับไปที่ 0 และส่งสัญญาณ carry ไปยัง Counter ตัวถัดไป 

ในวงจรนี้ เราใช้ Diode ร่วมกับตัวต้านทานเพื่อทำการรีเซ็ต Counter ตัวที่สองเมื่อมันนับถึง 6 แทนการใช้ AND gate ซึ่งเป็นวิธีที่ง่ายและประหยัดอุปกรณ์มากกว่า 

ในการนับหลักสิบของวินาทีก่อนจะถึง 6 (0110) ไดโอดแต่ละตัวจะได้รับลอจิก 0 จาก output ของ  74'390  การต่อวงจรแบบนี้เข้าข่าย AND gate แบบจำลอง ซึ่งทำให้ขา 2 ของ 74390 เป็นลอจิก 0 อยู่ตลอดเวลา 

เมื่อมันนับถึง 6 (0110) ไดโอดทั้งสองตัวจะได้รับลอจิก 1 จาก output ของ 74'390 ทำให้ขา 2 ของ 74390 เป็นลอจิก 1 สภาวะเช่นนี้ทำให้มันรีเซ็ต 74390 ให้กลับไปที่ 0 พร้อมทั้งส่งสัญญาณ carry ไปยัง Counter ตัวถัดไปเพื่อเพิ่มค่าของหลักนาทีต่อไป     

เพื่อให้เข้าใจง่ายขึ้น จากการเชื่อมต่อในวงจร เราสามารถดูตารางความจริงการนับของ Counter วินาทีได้ดังนี้

<b> ตารางที่ 1 </b> ตารางความจริงการนับของ Counter วินาที (QA = LSB, QD = MSB)
| นับ | 1QA | 1QB | 1QC | 1QD | 1MR | เหตุการณ์ |
| --- | --- | --- | --- | --- | --- | --- |
| 0 | 0 | 0 | 0 | 0 | 1 | นับต่อไป |
| 1 | 1 | 0 | 0 | 0 | 1 | นับต่อไป |
| 2 | 0 | 1 | 0 | 0 | 1 | นับต่อไป |
| 3 | 1 | 1 | 0 | 0 | 1 | นับต่อไป |
| 4 | 0 | 0 | 1 | 0 | 1 | นับต่อไป |
| 5 | 1 | 0 | 1 | 0 | 1 | นับต่อไป |
| 6 | 0 | 1 | 1 | 0 | 0 | รีเซ็ต (1QA - 1QD เป็น 0000) |
| 7 | 1 | 1 | 1 | 0 | 0 | ไม่สามารถเกิดขึ้นได้ |

### Counter 00-59 นาที

<p align="center">
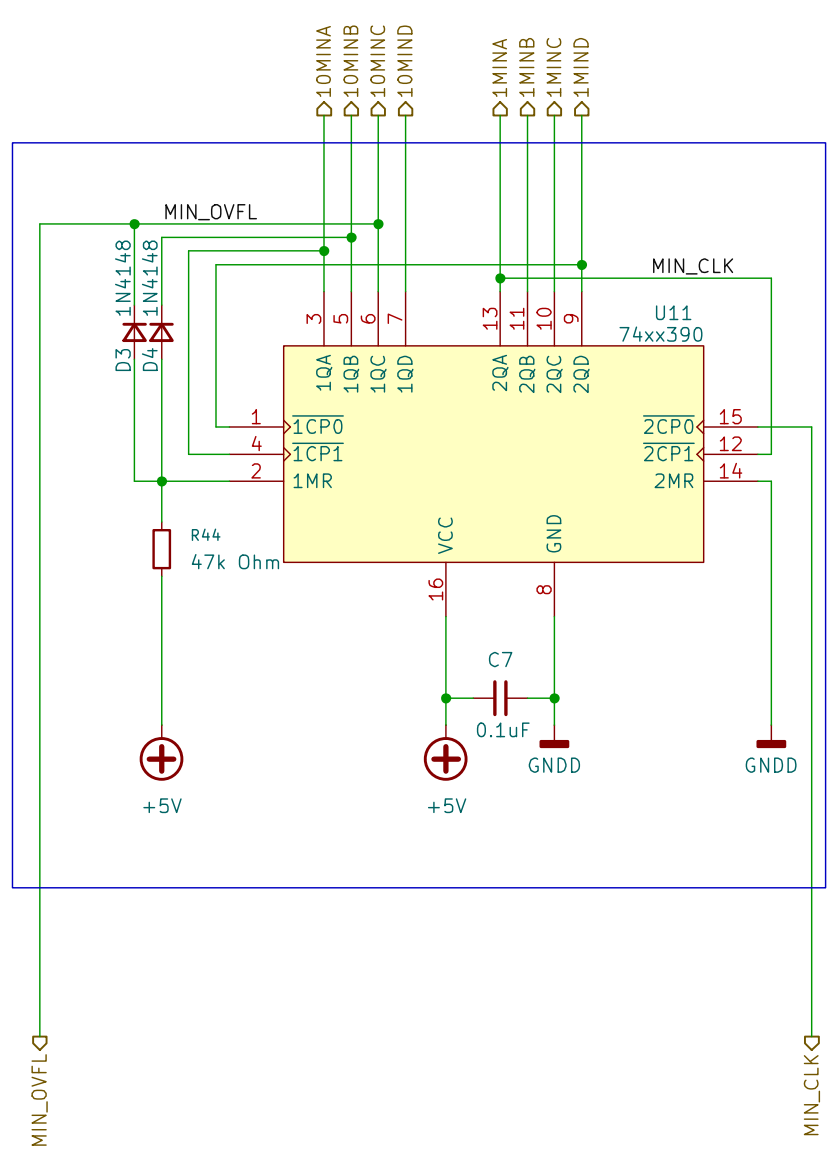
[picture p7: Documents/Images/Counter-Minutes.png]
Counter Minutes

<br> <b>รูปที่ 2 </b> วงจรนับนาที
</p>

การทำงานของ Counter นาทีจะเหมือนกับ Counter วินาที โดยใช้ Counter mod-10 สำหรับหลักหน่วยนาที และ Counter mod-6 สำหรับหลักสิบของนาที ซึ่งจะทำงานร่วมกันเพื่อให้นับได้ตั้งแต่ 00 ถึง 59 นาที

### Counter 00-23 ชั่วโมง
<p align="center">
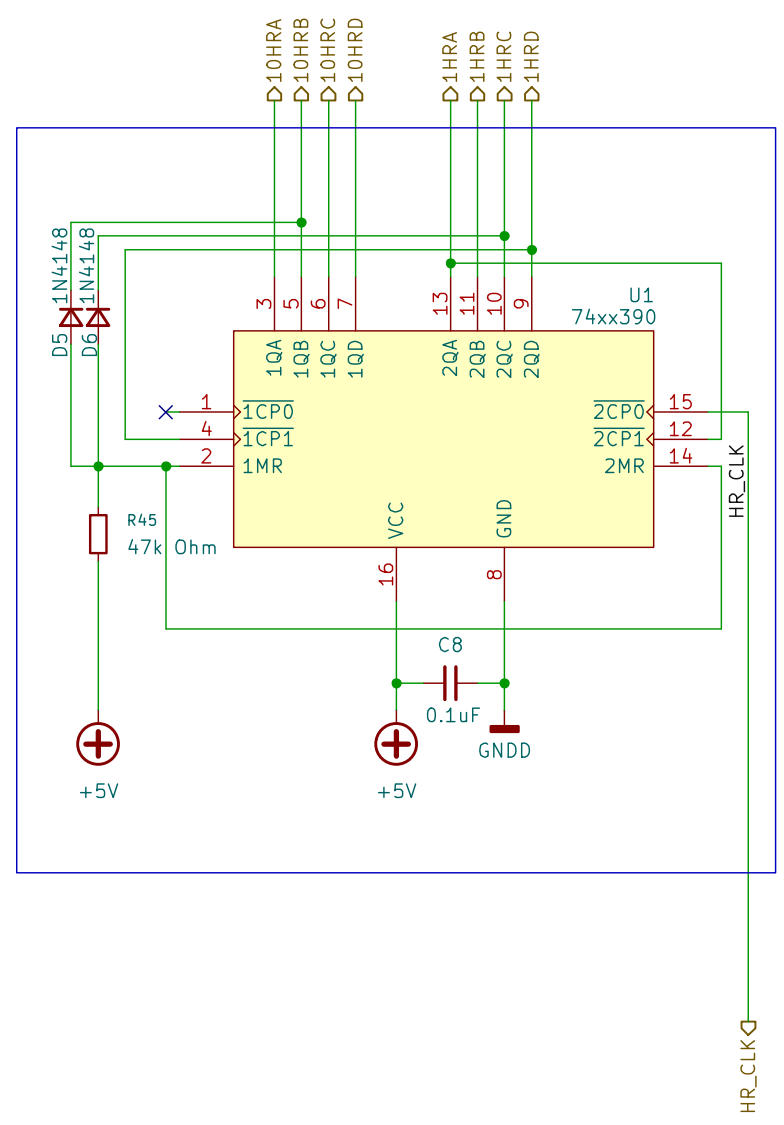
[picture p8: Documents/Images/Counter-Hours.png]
Counter Hours

<br> <b>รูปที่ 3 </b> วงจรนับชั่วโมง
</p>

วงจรนับชั่วโมงจะมีความซับซ้อนมากขึ้นเล็กน้อย เนื่องจากต้องนับได้ตั้งแต่ 00 ถึง 23 ชั่วโมง  โชคดีที่เรามี counter mod-10 จำนวนสองตัวเรียงกันอยู่แล้ว แนวทางที่ง่ายที่สุดคือ การรีเซ็ต Counter ทั้งคู่เมื่อมันนับถึง 24 (0010 0100) โดยใช้ AND gate หรือ Diode ร่วมกับ Resistor แบบที่เราทำในวงจรนับหลักสิบของวินาที

แต่สิ่งที่ต่างจากวงจรนับวินาทีและนับนาทีคือ วงจรนี้เราจะนำเอาเลข 2 ของ Counter หลักสิบชั่วโมง (ซึ่งเป็นลอจิก 1 เมื่อมันนับถึง 2) มาร่วมกับเลข 4 ของ Counter หลักหน่วยชั่วโมง (ซึ่งเป็นลอจิก 1 เมื่อมันนับถึง 4) มาทำการรีเซ็ต Counter ทั้งคู่เมื่อมันนับถึง 24 (0010 0100) เพื่อให้มันรีเซ็ตกลับไปที่ 00 และเริ่มนับใหม่อีกครั้ง

1QA - 1QD เป็น output ของ Counter หลักสิบชั่วโมง ซึ่งจะนับจาก 0 ถึง 2 และเมื่อมันนับถึง 2 (0010) บิตที่ 3 จะเป็นลอจิก 1
2QA - 2QD เป็น output ของ Counter หลักหน่วยชั่วโมง ซึ่งจะนับจาก 0 ถึง 9 และเมื่อมันนับถึง 4 (0100) บิตที่ 2 จะเป็นลอจิก 1
(QA = LSB, QD = MSB)

เมื่อทั้งบิตที่ 2 ของ Counter หลักสิบชั่วโมงและบิตที่ 3 ของ Counter หลักหน่วยชั่วโมงเป็นลอจิก 1 พร้อมกัน มันจะให้เอาต์พุตเป็นลอจิก 1 ทำให้วงจรรีเซ็ตทำงาน รีเซ็ตทั้ง Counter หลักสิบชั่วโมงและหลักหน่วยชั่วโมงให้กลับไปที่ 00 และเริ่มนับใหม่อีกครั้ง

<b> ตารางที่ 2 </b> ตารางความจริงการนับของ Counter ชั่วโมง (QA = LSB, QD = MSB)

| นับ | 1QD | 1QC | 1QB | 1QA | 1MR | 2QD | 2QC | 2QB | 2QA | 2MR | เหตุการณ์ |
| --- | --- | --- | --- | --- | --- | --- | --- | --- | --- | --- | --- |
| 00 | 0 | 0 | 0 | 0 | 0 | 0 | 0 | 0 | 0 | 0 | นับต่อไป |
| 01 | 0 | 0 | 0 | 0 | 0 | 0 | 0 | 0 | 1 | 0 | นับต่อไป |
| 02 | 0 | 0 | 0 | 0 | 0 | 0 | 0 | 1 | 0 | 0 | นับต่อไป |
| 03 | 0 | 0 | 0 | 0 | 0 | 0 | 0 | 1 | 1 | 0 | นับต่อไป |
| 04 | 0 | 0 | 0 | 0 | 0 | 0 | 1 | 0 | 0 | 0 | นับต่อไป |
| 05 | 0 | 0 | 0 | 0 | 0 | 0 | 1 | 0 | 1 | 0 | นับต่อไป |
| 06 | 0 | 0 | 0 | 0 | 0 | 0 | 1 | 1 | 0 | 0 | นับต่อไป |
| 07 | 0 | 0 | 0 | 0 | 0 | 0 | 1 | 1 | 1 | 0 | นับต่อไป |
| 08 | 0 | 0 | 0 | 0 | 0 | 1 | 0 | 0 | 0 | 0 | นับต่อไป |
| 09 | 0 | 0 | 0 | 0 | 0 | 1 | 0 | 0 | 1 | 0 | นับต่อไป |  
| 10 | 0 | 0 | 0 | 1 | 0 | 1 | 0 | 1 | 0 | 0 | นับต่อไป |
| 11 | 0 | 0 | 0 | 1 | 0 | 1 | 0 | 1 | 1 | 0 | นับต่อไป |
| 12 | 0 | 0 | 0 | 1 | 0 | 1 | 1 | 0 | 0 | 0 | นับต่อไป |
| 13 | 0 | 0 | 0 | 1 | 0 | 1 | 1 | 0 | 1 | 0 | นับต่อไป |
| 14 | 0 | 0 | 0 | 1 | 0 | 1 | 1 | 1 | 0 | 0 | นับต่อไป |
| 15 | 0 | 0 | 0 | 1 | 0 | 1 | 1 | 1 | 1 | 0 | นับต่อไป |  
| 16 | 0 | 0 | 1 | 0 | 0 | 0 | 0 | 0 | 0 | 0 | นับต่อไป |
| 17 | 0 | 0 | 1 | 0 | 0 | 0 | 0 | 0 | 1 | 0 | นับต่อไป |
| 18 | 0 | 0 | 1 | 0 | 0 | 0 | 0 | 1 | 0 | 0 | นับต่อไป |
| 19 | 0 | 0 | 1 | 0 | 0 | 0 | 0 | 1 | 1 | 0 | นับต่อไป |
| 20 | 0 | 0 | 1 | 0 | 0 | 0 | 1 | 0 | 0 | 0 | นับต่อไป |
| 21 | 0 | 0 | 1 | 0 | 0 | 0 | 1 | 0 | 1 | 0 | นับต่อไป |
| 22 | 0 | 0 | 1 | 0 | 0 | 0 | 1 | 1 | 0 | 0 | นับต่อไป |
| 23 | 0 | 0 | 1 | 0 | 1 | 0 | 1 | 1 | 1 | 1 | รีเซ็ต (1QA - 2QD เป็น 0000) | 
| 24 | 0 | 0 | 0 | 0 | 0 | 0 | 0 | 0 | 0 | 0 | ไม่สามารถเกิดขึ้นได้ |

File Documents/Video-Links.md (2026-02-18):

## 🛠️ ขออภัย ยังไม่พร้อมบริการ 
## [👈](../Readme.md) คุณจำเป็นต้องอ่านแล้วแหละ

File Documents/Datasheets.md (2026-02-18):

# Datasheets

## ไอซีหลักที่ใช้ในวงจร

| # | Part | Details | Datasheet |
| --- | --- | --- | --- |
| 1 | CD4543 | CMOS BCD-to-Seven-Segment Latch/Decoder/Driver for Liquid-Crystal Displays | https://www.ti.com/lit/gpn/cd4543b |
| 2 | NE555 | Single Precision Timer | https://www.ti.com/lit/gpn/ne555 |
| 3 | SN74LS157 | Quadruple 2-Line To 1-Line Data Selectors/Multiplexers | https://www.ti.com/lit/gpn/sn74ls157 |
| 4 | SN7414 | 6-ch, 4.75-V to 5.25-V bipolar inverters with Schmitt-Trigger inputs | https://www.ti.com/lit/gpn/sn7414 |
| 5 | SN7474 | Dual D-Type Positive-Edge-Triggered Flip-Flops With Preset And Clear | https://www.ti.com/lit/gpn/sn74s74 |
| 6 | SN74LS390 | Dual 4-Bit Decade Counters | https://www.ti.com/lit/gpn/sn74ls390 |

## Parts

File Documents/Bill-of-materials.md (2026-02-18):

# Bill of Materials (รายการอุปกรณ์ที่ใช้ในโครงงาน)

| No  | Component | Part No | Details | Qty | Unit | Remark |
| --- | --- | --- | --- | --- | --- | --- |
| 1 | LED 7 Segment | TOD-5261AE  | 7 segment 2 Digits | 3 | ตัวตัว | |
| 2 | ไอซีถอดรหัส BCD เป็น7 Segment | CD4543DB | BCD to 7 segment decoder | 6 | ตัว | |
| 3 | ไอซีนับเลขแบบ Decade Counter | SN74LS390N  | Decade Counter | 3 | ตัว | |
| 4 | ไอซี Hex Schmitt-trigger Inverter | SN74LS14 | Hex Schmitt-trigger Inverter | 1 | ตัว | |
| 5 | ไอซี Dual D-FF | SN74LS74 | Dual D-FF | 1 | ตัว | |
| 6 | ไอซี Quad MUX 2:1 | SN74LS157 | Quad MUX 2:1 | 1 | ตัว | |
| 7 | ไอซี Timer | NE555 | IC Timer | 1 | ตัว | |
| 8 | ไดโอด | 1N4148 | Diode | 6 | ตัว | |
| 9 | ตัวต้านทาน | R 330 Ω | R 1/4 W  ±5% | 42  | ตัว | |
| 10  | ตัวต้านทาน | R 10kΩ | R 1/4 W ±5% | 6 | ตัว | |
| 11  | ตัวต้านทาน | R 47kΩ | R 1/4 W ±5% | 3 | ตัว | |
| 12  | ตัวเก็บประจุ | C 0.1uF 50V | Ceramic capacitor | 17  | ตัว | |
| 13  | ตัวเก็บประจุ | C 47uF 16V  | Electrolyte | 1 | ตัว | |
| 14  | ตัวเก็บประจุ | C 10nF 50V  | Ceramic capacitor | 1 | ตัว | |
| 15  | ซ็อกเก็ต | | Socket 8 Pins | 1 | ตัว | |
| 16  | ซ็อกเก็ต | | Socket 14 Pins | 2 | ตัว | |
| 17  | ซ็อกเก็ต | | Socket 16 Pins | 10  | ตัว | |
| 18  | ขั้วต่อสำหรับ bcd counter | | Connector 1 $\times$ 4 Pins | 12  | ตัว | |
| 19  | ขั้วต่อสำหรับไฟเลี้ยงและ gnd | | Connector 2 $\times$ 2 Pins | 4 | ตัว | |
| 20  | ขั้วต่อสำหรับเสียบ 7 Segment | | Connector 1 $\times$ 9 Pins | 6 | ตัว | แนะนำให้ใส่ จะได้ถอดเสียบ 7 Segment ได้ ในกรณีที่ทำพัง |
| 21  | PCB เอนกประสงค์ | | ขนาดพอเหมาะ ในตัวอย่างใช้ขนาด  12 $\times$ 8 cm | 1 | แผ่น | เลือกขนาดคามความถนัดและสะดวกในการบัดกรี |

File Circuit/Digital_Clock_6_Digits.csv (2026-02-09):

Id | Designator | Footprint | Quantity | Designation | Supplier and ref
1 | R23,R3,R13,R38,R33,R34,R42,R28,R18,R31,R29,R30,R17,R1,R5,R12,R4,R37,R35,R6,R21,R22,R7,R15,R25,R24,R2,R26,R14,R8,R32,R19,R36,R39,R41,R9,R27,R20,R10,R40,R11,R16 | R_0603_1608Metric | 42 | 220
2 | J5,J6,J3,J4,J2,J1 | PinHeader_1x04_P2.54mm_Vertical | 6 | Conn_01x04
3 | U2,U10,U3,U9,U8,U4 | DIP-16_W7.62mm_Socket_LongPads | 6 | 4543
4 | U6,U5,U7 | DA56-11CGKWA | 3 | DA56-11SURKWA

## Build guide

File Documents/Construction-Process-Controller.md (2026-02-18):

###  การประกอบวงจร 

วงจร controller  เป็นส่วนที่สำคัญมากในโครงงานนี้ เพราะเป็นส่วนที่ทำหน้าที่ควบคุมการทำงานของวงจรนับเวลา (Counter) และส่งสัญญาณไปยังส่วนแสดงผล (Display) เพื่อให้สามารถแสดงผลตัวเลขได้อย่างถูกต้องและสวยงาม ดังนั้น การประกอบวงจร controller จึงต้องทำอย่างระมัดระวังและมีความละเอียดสูง เพื่อให้แน่ใจว่าวงจรจะทำงานได้อย่างถูกต้องและไม่มีปัญหาในการใช้งานในภายหลัง

#### วงจร controller ประกอบด้วยส่วนหลัก ๆ ดังนี้
- ส่วนสร้างสัญญาณ Clock ซึ่งจะใช้ไอซี 555 ในการสร้างสัญญาณ Clock ที่มีความถี่ 1Hz เพื่อให้สามารถนับเวลาได้
- ส่วนควบคุมเส้นทางของสัญญาณ Clock ซึ่งจะใช้ไอซี 74157 เป็นตัวเลือกในการส่งสัญญาณ Clock ไปยังวงจรนับเวลา (Counter) หรือจะส่งสัญญาณจากการกดปุ่มเพื่อตั้งเวลาไปยังวงจรนับเวลา (Counter) แทน
- วงจรนี้จะมีส่วนแสดงผลด้วย LED สองดวงคือ LED สีแดงที่จะแสดงสถานะการทำงานของสัญญาณ Clock และ LED สีเขียวที่จะแสดงสถานะการทำงานของปุ่มตั้งเวลา
  - โดย LED สีแดงจะกระพริบตามสัญญาณ Clock และไม่สนใจวงจรส่วนอื่น ๆ ในระบบ
  - ส่วน LED สีเขียวจะติดเมื่อมีการกดปุ่มตั้งเวลา และจะดับเมื่อกดปุ่มตั้งเวลาอีกครั้ง โดยความร่วมมือจาก D-FF เบอร์ 7474 นั่นเอง ถ้า LED สีเขียวติดอยู่ แสดงว่าโหมดตั้งเวลาทำงานอยู่ และถ้า LED สีเขียวดับ แสดงว่าโหมดนาฬิกากำลังทำงานอยู่

<p align="center">
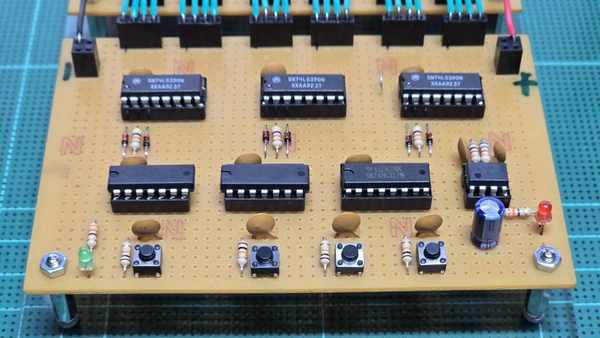
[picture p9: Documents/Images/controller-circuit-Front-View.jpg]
Controller Circuit Front View

</p>

<p align="center">
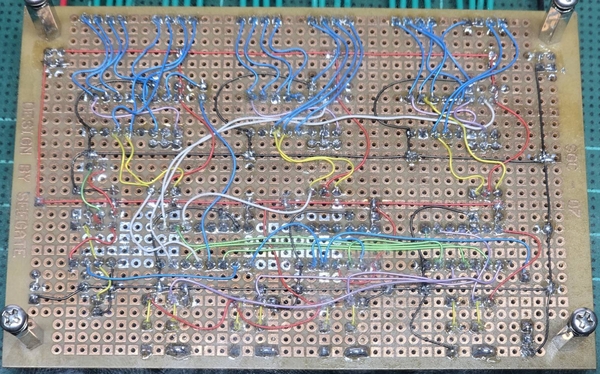
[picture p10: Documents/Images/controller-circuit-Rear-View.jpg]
Controller Circuit Rear View

</p>

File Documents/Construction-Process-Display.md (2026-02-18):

## ขั้นตอนการประกอบวงจรและข้อควรระวัง
### การบัดกรี 7-Segment
<p align="center">
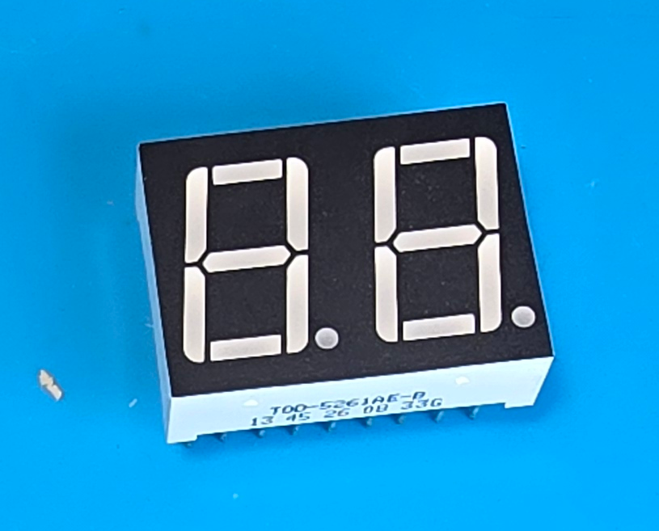
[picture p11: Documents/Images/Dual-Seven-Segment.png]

</p>

7 segment เป็นส่วนที่สำคัญที่สุดของโครงงานนี้ เพราะเป็นส่วนที่แสดงผลตัวเลขออกมาให้เราเห็น ดังนั้นการบัดกรี 7-Segment จึงต้องระมัดระวังเป็นพิเศษ เพื่อให้ได้ผลลัพธ์ที่ดีและลดความเสี่ยงในการทำพัง เราจะไม่บัดกรี 7-Segment ลงบนแผ่นผรินท์โดยตรง แต่จะใช้ขั้วต่อ (Connector) เพื่อเสียบแทนการบัดกรี ซึ่งจะช่วยให้เราสามารถถอดและเสียบ 7-Segment ได้ง่ายขึ้นในกรณีที่ทำพัง หรือถ้าต้องการเปลี่ยน 7-Segment ใหม่

<p align="center">
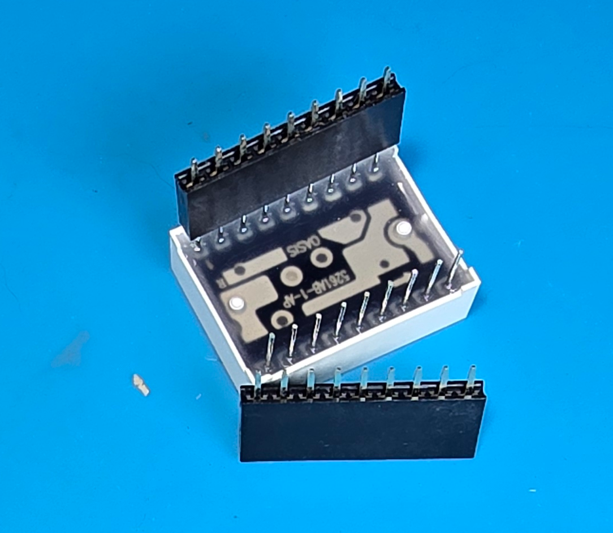
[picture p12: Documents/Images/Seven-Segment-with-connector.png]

</p>

### การบัดกรีไอซี

การบัดกรีไอซีก็เช่นเดียวกันกับ 7-Segment เราจะไม่บัดกรีไอซีลงบนแผ่นพิมพ์โดยตรง แต่จะใช้ขั้วต่อ (Socket) เพื่อเสียบแทนการบัดกรี ซึ่งจะช่วยให้เราสามารถถอดและเสียบไอซีได้ง่ายขึ้นในกรณีที่ทำพัง หรือถ้าต้องการเปลี่ยนไอซีใหม่

<p align="center">
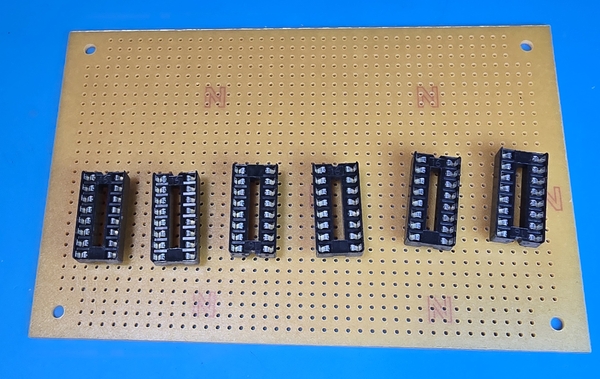
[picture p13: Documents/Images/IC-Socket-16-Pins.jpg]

</p>

### การวางตำแหน่งอุปกรณ์ส่วนแสดงผล

การวางตำแหน่งอุปกรณ์ส่วนแสดงผล (Display) ควรจะวางไว้ในตำแหน่งที่เหมาะสม เพื่อให้สามารถมองเห็นได้ชัดเจน และไม่ถูกบังด้วยอุปกรณ์อื่น ๆ ในวงจร นอกจากนี้ยังควรจะวางไว้ในตำแหน่งที่สะดวกในการเชื่อมต่อกับส่วนอื่น ๆ ของวงจร เช่น Counter และ Controller เพื่อให้การเดินสายและการเชื่อมต่อเป็นไปอย่างง่ายดายและไม่ซับซ้อน

<p align="center">
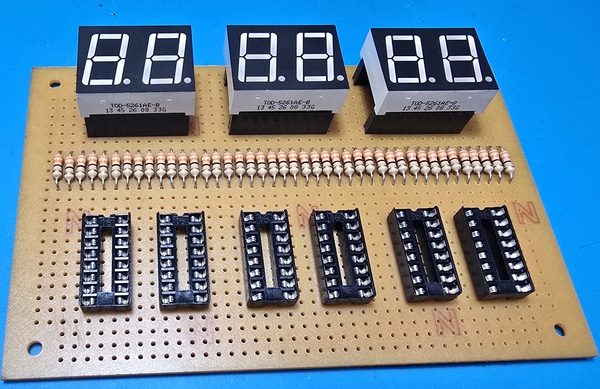
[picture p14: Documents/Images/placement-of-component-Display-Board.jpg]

</p>

จากรูป เป็นตัวอย่างการวางตำแหน่งอุปกรณ์ส่วนแสดงผล (Display) ที่สะดวกต่อการเชื่อมต่อกับส่วนอื่น ๆ ของวงจร และสามารถมองเห็นได้ชัดเจน นักศึกษาสามารถปรับเปลี่ยนตำแหน่งได้ตามความสะดวกและความถนัดในการประกอบวงจรของแต่ละคน

ที่เห็นตัวต้านทานวางเรียบ ๆ กันอยู่ในรูป เป็นเพราะเราพับขามันไว้ หลังจากที่เสียบลงบนบอร์ด เพื่อไม่ให้มันหลุดออกมา และเราจะดัดขาให้มันตั้งขึ้นมาในขั้นตอนการบัดกรี   

### การบัดกรีอุปกรณ์ที่วางไว้ในตำแหน่งที่เหมาะสมแล้ว

<p align="center">
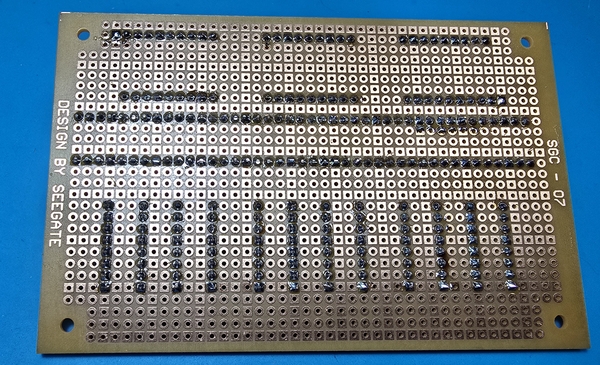
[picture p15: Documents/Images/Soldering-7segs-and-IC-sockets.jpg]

</p>

จากรูป เป็นตัวอย่างการบัดกรีอุปกรณ์ที่วางไว้ในตำแหน่งที่เหมาะสมแล้ว ซึ่งจะช่วยให้การบัดกรีเป็นไปอย่างง่ายดายและไม่ซับซ้อน นักศึกษาควรจะบัดกรีอย่างระมัดระวัง และตรวจสอบการเชื่อมต่อหลังจากที่บัดกรีเสร็จแล้ว เพื่อให้แน่ใจว่าไม่มีการเชื่อมต่อผิดพลาดหรือขาดหายไป

<p align="center">
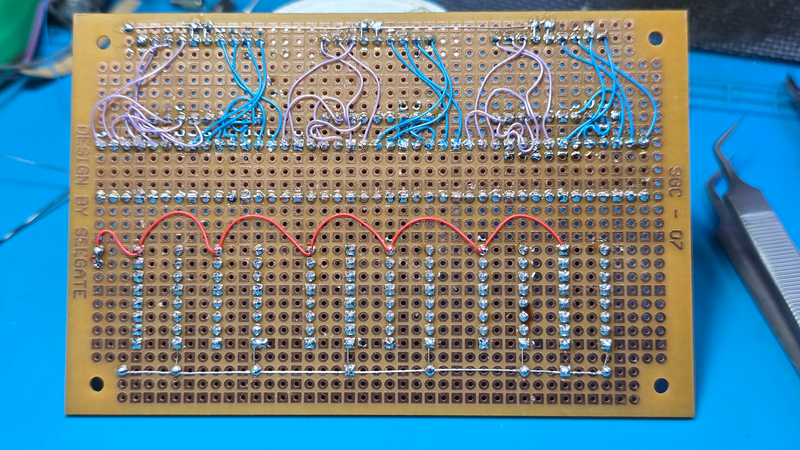
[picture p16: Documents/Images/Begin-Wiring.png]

</p>

เมื่อบัดกรี socket กับ connector รวมถึงตัวต้านทานเสร็จแล้ว ต่อไปเราก็จะเริ่ม wiring สายกัน
ถ้าให้ดีนักศึกษาควรจะหาสาย wiring ไว้หลาย ๆ สีและจัดหมวดหมู่ตามสีที่เหมาะสม
เช่น 
- สายสีแดงจะแทน power supply
- สายสีดำ แทนกราวด์
- สายสีเขียวอาจจะเป็นสัญญาณ seven segment ก่อนผ่านตัวต้านทาน
- สายสีฟ้าเป็นสายจากตัวต้านทานไปยัง seven segment เป็นต้น 
ทั้งนี้ ก็เพื่อให้การ wiring สายเป็นไปอย่างง่ายดายและไม่ซับซ้อน

<p align="center">

</p>

เมื่อบัดกรีเสร็จแล้ว ให้ทำการตรวจสอบให้ถูกต้องครบถ้วน

เพื่อให้การตรวจสอบได้ผลดี นักศึกษาควรจะแบ่งหน้าที่กันตรวจสอบ โดยการให้คนที่ไม่ได้บัดกรีเป็นคนตรวจสอบ
เพราะจะได้ไม่เข้าข้างตัวเองว่าบัดดีครบถ้วนดีแล้ว

## การทดสอบวงจรที่บัดกรีเสร็จแล้ว

ขั้นตอนถัดไปคือเราจะต้องทดสอบบอร์ดที่เราบัดกรีแล้วโดยการทดสอบทีละส่วน โดยยังไม่ต้องเสียบไอซีหรือ 7-Segment ลงไปใน socket หรือ connector การทดสอบนี้ ควรทดสอบ 100% ของจุดเชื่อมต่อทั้งหมด

วิธีการทดสอบที่แนะนำคือการใช้มัลติมิเตอร์วัดความต่อเนื่องของสัญญาณตามจุดที่เชื่อมต่อกันตามวงจร (Continuity Test) เพื่อให้แน่ใจว่าไม่มีการเชื่อมต่อผิดพลาดหรือขาดหายไป และเพื่อให้แน่ใจว่าไม่มีการช็อตกันของสัญญาณที่ไม่ควรจะเชื่อมต่อกัน

ข้อผิดพลาดที่ร้ายแรงที่สุดคือการเชื่อมต่อสายไฟผิดพลาด ที่ทำให้ไฟเลี้ยง (Power Supply) ไปเชื่อมต่อกับกราวด์ (Ground) 
ถ้าเราต่อไฟเลี้ยงมาจากพอร์ต USB ของคอมพิวเตอร์แล้วเกิดการช็อตกันแบบนี้ อาจจะทำให้คอมพิวเตอร์ของเราพังได้เลย ดังนั้นการตรวจสอบความต่อเนื่องของสัญญาณจึงเป็นสิ่งที่สำคัญมาก ๆ ในขั้นตอนนี้

จุดที่สำคัญลำดับต่อมาคือ แต่ละเซกเมนต์ของ 7-Segment ต้องมีการเชื่อมต่อกับตัวต้านทานที่ถูกต้อง และตัวต้านทานต้องเชื่อมต่อกับขาออกของไอซีถอดรหัส BCD เป็น 7-Segment อย่างถูกต้องด้วยเช่นกัน 
ถ้าหากมีการเชื่อมต่อผิดพลาดในจุดนี้ อาจจะทำให้ 7-Segment แสดงผลผิดพลาด หรือไม่แสดงผลเลยก็ได้ ดังนั้นการตรวจสอบความต่อเนื่องของสัญญาณในจุดนี้จึงเป็นสิ่งที่สำคัญมาก ๆ เช่นกัน

เมื่อทดสอบความต่อเนื่องเรียบร้อยแล้วก็สามารถเสียบ seven segment และ IC ถอดรหัส BCD เป็น 7-Segment (CD4543) ลงไปใน socket หรือ connector ได้

## ภาพรวมของบอร์ดที่ประกอบเสร็จแล้ว

### ภาพด้านหน้าของบอร์ดที่ประกอบเสร็จแล้ว

<p align="center">
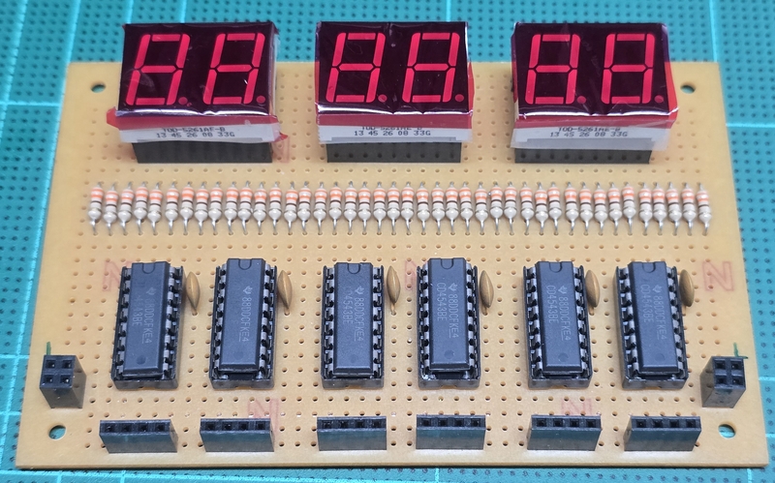
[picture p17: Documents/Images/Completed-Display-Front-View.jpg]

</p>

ด้านหน้าของบอร์ดที่ประกอบเสร็จแล้ว จะเห็นว่า 7-Segment ถูกติดตั้งอยู่ในตำแหน่งที่เหมาะสม ซึ่งจะช่วยให้การแสดงผลตัวเลขออกมาได้ชัดเจนและสวยงาม นอกจากนี้ยังเห็นตัวต้านทานที่ถูกวางไว้เรียงกันอย่างเป็นระเบียบ ไม่รบกวนการมองของผู้ใช้งาน และยังช่วยให้การบัดกรีเป็นไปอย่างง่ายดายและไม่ซับซ้อนอีกด้วย

### ภาพด้านหลังของบอร์ดที่ประกอบเสร็จแล้ว

<p align="center">
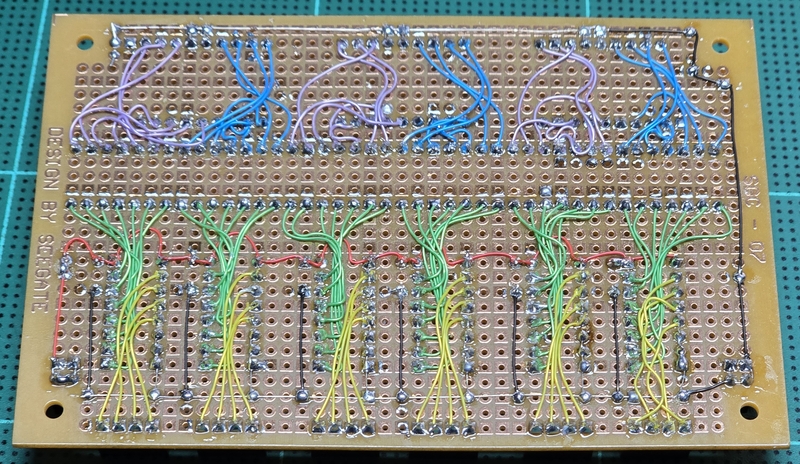
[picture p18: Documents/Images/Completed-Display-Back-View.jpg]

</p>

ด้านหลังของบอร์ดที่ประกอบเสร็จแล้ว จะเห็นว่าการเดินสายและการเชื่อมต่อเป็นไปอย่างมีระเบียบ อาจจะมีบางสายที่ยาวเกินไป นั่นก็เพื่อให้สามารถแก้ไขได้ง่ายในกรณีที่มีการเชื่อมต่อผิดพลาดหรือขาดหายไป

สิ่งสำคัญที่สุดในการบัดกรีคือ ฉนวนของสายไฟจะสามารถละลายได้ง่าย สายไฟเส้นที่พาดกันอาจจะช๊อตกันได้ ดังนั้นในขณะให้ความร้อนแก่จุดที่ต้องการบัดกรี เราควรจะระมัดระวังไม่ให้ความร้อนนั้นไปทำลายฉนวนของสายไฟที่อยู่ใกล้เคียง 

การพาดการของสายไฟ เป็นสิ่งที่ไม่สามารถหลีกเลี่ยงได้ แต่ในขณะบัดกรีเราสามารถที่จะยกสายไฟให้ลอยขึ้นเล็กน้อย ซึ่งจะทำให้มีโอกาสในการช็อตกันลดลง

## สรุป
การประกอบวงจรส่วนแสดงผล (Display) เป็นขั้นตอนที่สำคัญมาก ๆ ในโครงงานนี้ เพราะเป็นส่วนที่แสดงผลตัวเลขออกมาให้เราเห็น ดังนั้นการบัดกรีและการเดินสายในส่วนนี้จึงต้องระมัดระวังเป็นพิเศษ เพื่อให้ได้ผลลัพธ์ที่ดีและลดความเสี่ยงในการทำพัง การใช้ขั้วต่อ (Connector) และขั้วต่อไอซี (Socket) จะช่วยให้เราสามารถถอดและเสียบอุปกรณ์ได้ง่ายขึ้น (ในกรณีที่ทำพัง หรือถ้าต้องการเปลี่ยนอุปกรณ์ใหม่) นอกจากนี้ยังควรจะวางตำแหน่งอุปกรณ์ในตำแหน่งที่เหมาะสม เพื่อให้สามารถมองเห็นได้ชัดเจน และไม่ถูกบังด้วยอุปกรณ์อื่น ๆ ในวงจร และควรจะวางไว้ในตำแหน่งที่สะดวกในการเชื่อมต่อกับส่วนอื่น ๆ ของวงจร เช่น Counter และ Controller เพื่อให้การเดินสายและการเชื่อมต่อเป็นไปอย่างง่ายดายและไม่ซับซ้อน

ส่วน Display เปรียบเสมือนหน้าต่างที่เรามองเข้าไปในโลกของโครงงานนี้ ดังนั้นการประกอบและการบัดกรีในส่วนนี้จึงต้องทำด้วยความระมัดระวังและความใส่ใจ เพื่อให้ได้ผลลัพธ์ที่ดีที่สุด และเพื่อให้โครงงานของเราสามารถแสดงผลตัวเลขออกมาได้อย่างถูกต้องและสวยงามที่สุด

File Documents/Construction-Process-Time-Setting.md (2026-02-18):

# ส่วนตวบคุมการทำงานและตั้งเวลา (Controller and Time Setting)

เนื้อหาในส่วนนี้จะอธิบายเกี่ยวกับวงจรตั้งเวลา (Time Setting Circuit) ซึ่งเป็นส่วนที่สำคัญมากในโครงงานนี้ เพราะเป็นส่วนที่ทำหน้าที่ให้ผู้ใช้งานสามารถตั้งค่าเวลา (ชั่วโมง นาที วินาที) ได้อย่างง่ายดายและสะดวกสบาย โดยไม่ต้องไปแก้ไขวงจรนับเวลา (Counter) หรือส่วนแสดงผล (Display) แต่อย่างใด

<p align="center">
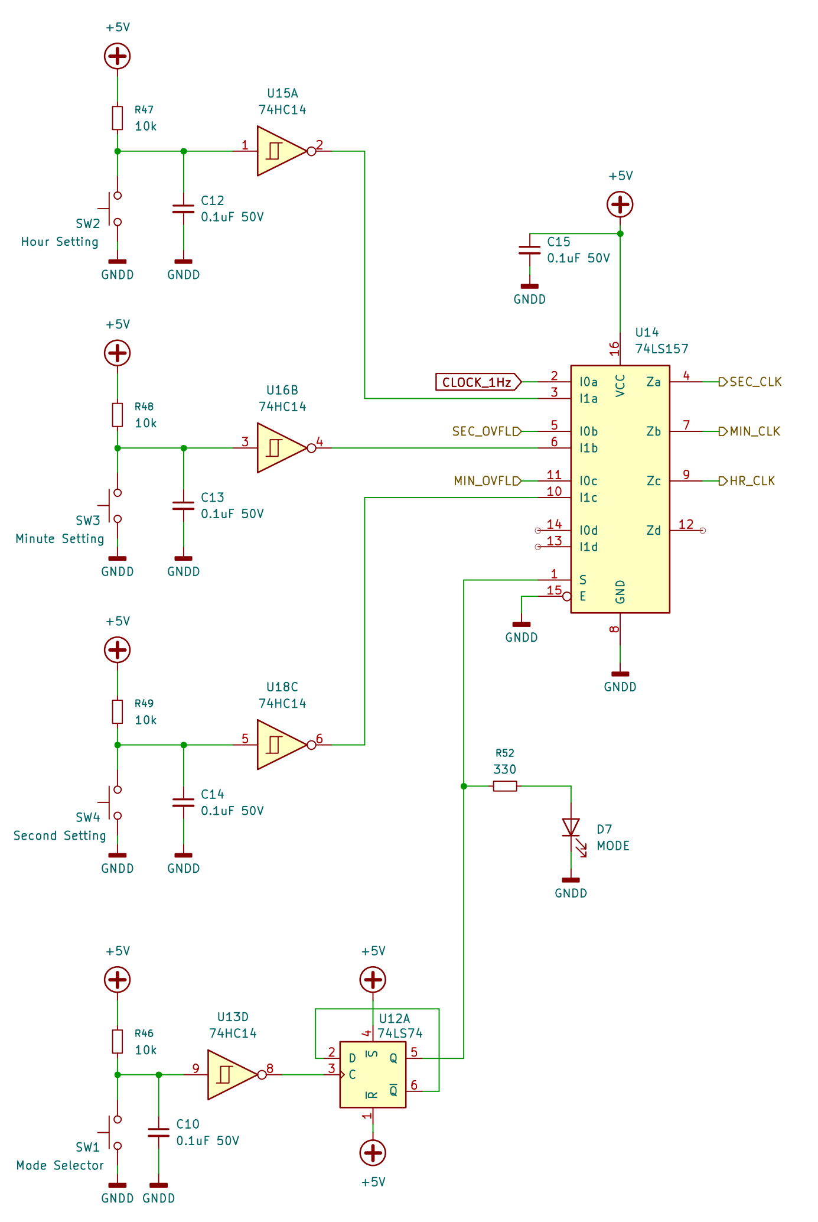
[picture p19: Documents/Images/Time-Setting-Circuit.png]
Time Setting Circuit

<br><b>รูปที่ 1</b> วงจรรวมของระบบควบคุมและตั้งเวลา 
</p>

วงจรตั้งเวลานี้จะประกอบด้วยส่วนหลัก ๆ ดังนี้

### 1. ปุ่มกด (Push Button) เลือกโหมดการทำงาน

ปุ่มกดเลือกโหมดการทำงาน ใช้เพื่อกำหนดให้นาฬิกาของเราเดินตามปกติหรือตั้งเวลาได้ ปุ่มกดนี้จะไปควบคุมการทำงานของ D-FF 74LS74 ที่ใช้ในการควบคุมโหมดการทำงานของวงจรตั้งเวลา (Time Setting Circuit) โดยจะทำหน้าที่เป็น toggle switch แบบสัมผัสด้วยการกดปุ่มเดียว ซึ่งจะช่วยให้ผู้ใช้งานสามารถสลับโหมดการทำงานได้อย่างง่ายดายและสะดวกสบาย โดยไม่ต้องไปแก้ไขวงจรนับเวลา (Counter) หรือส่วนแสดงผล (Display) แต่อย่างใด

แต่การต่อวงจรง่าย ๆ กลับส่งผลให้มีปัญหาที่เกิดขึ้น นั่นคือสัญญาณจากปุ่มกดจะมีการสั่นไหว (Bounce) ซึ่งอาจจะเกิดจากหน้าสัมผัสทางแมคานิกส์ของสวิตช์ไม่เป็นไปตามอุดมคติ พิจารณารูปที่ 2

<p align="center">
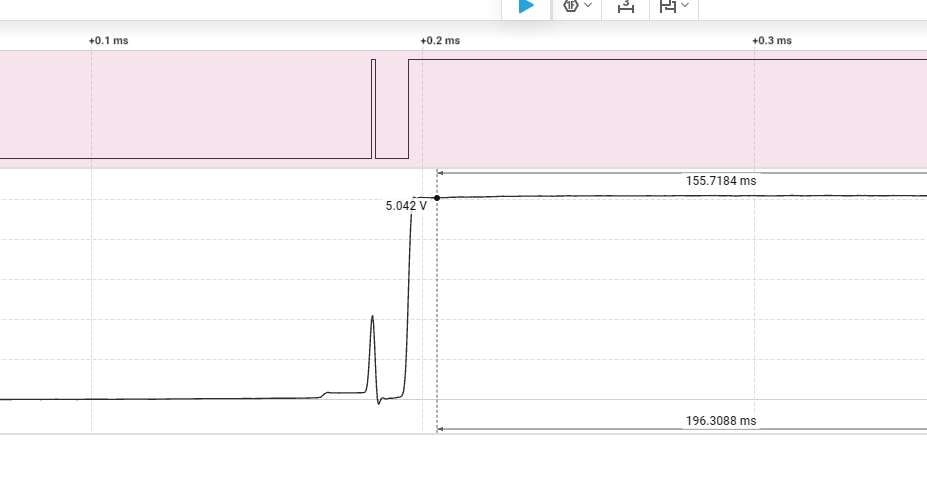
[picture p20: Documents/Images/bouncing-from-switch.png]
Bouncing from Switch

<br><b>รูปที่ 2</b> สัญญาณจากปุ่มกดที่ไม่มีวงจร Debounce จะมีการสั่นไหว (Bounce)
</p>

จากรูปที่ 2 จะเห็นว่าสัญญาณจากปุ่มกดที่ไม่มีวงจร Debounce จะมีการสั่นไหว (Bounce) ซึ่งอาจจะทำให้เกิดการตั้งค่าเวลาที่ผิดเพี้ยนได้ จากการทดลองกด Switch ที่ไม่มีวงจร debounce ติดกัน 5 ครั้ง  พบว่าในบางจังหวะ มีเอาต์พุตออกมาจาก switch มากถึง 11 ครั้ง ซึ่งจะทำให้เกิดการตั้งค่าเวลาที่ไม่ถูกต้องได้ 

<p align="center">
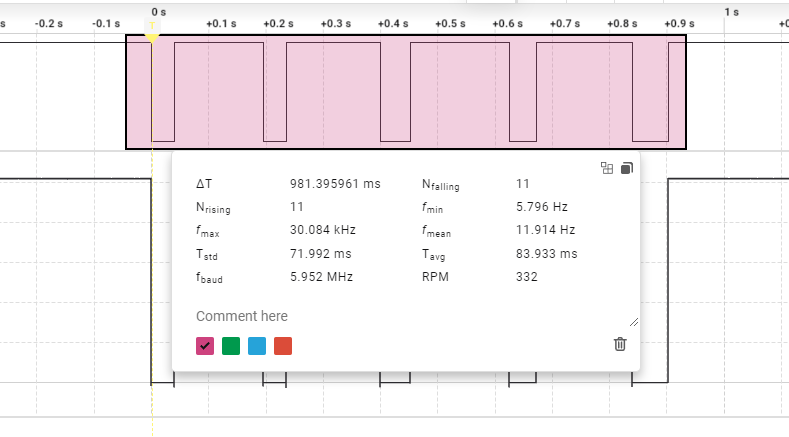
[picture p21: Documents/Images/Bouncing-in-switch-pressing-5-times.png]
Bouncing in Switch Pressing 5 Times

<br><b>รูปที่ 3</b> สัญญาณจากปุ่มกดที่ไม่มีวงจร Debounce ติดกัน 5 ครั้ง จะมีการสั่นไหว (Bounce) ทำให้มีเอาต์พุตออกมาจาก switch มากถึง 11 ครั้ง
</p>

จากปัญหาในรูปที่ 3 เราจึงต้องมีวงจร Debounce เพื่อช่วยให้สัญญาณจากปุ่มกดมีความเสถียรและไม่เกิดการสั่นไหว (Bounce) โดยการใส่ตัวเก็บประจุ (Capacitor) ร่วมกับตัวต้านทาน (Resistor) เพื่อกรองสัญญาณจากปุ่มกดให้มีความเสถียรและไม่เกิดการสั่นไหวได้อย่างมีประสิทธิภาพ 

วงจร Debounce นี้จะเป็นวงจร RC ที่ประกอบด้วยตัวต้านทานและตัวเก็บประจุ โดยมีค่า  $R = 10kΩ$ และ $C = 100nF$ ซึ่งจะช่วยให้สัญญาณจากปุ่มกดไม่เกิดการสั่นไหวที่จะทำให้เกิดการผิดเพี้ยนในการนับเลขได้ 

จากที่ได้เรียนวงจรไฟฟ้า พบว่าค่า time constant ของวงจร RC จะเท่ากับ $R \times C$ ซึ่งในกรณีนี้จะเท่ากับ $10kΩ \times 100nF = 1ms$ ซึ่งเป็นค่าที่เหมาะสมสำหรับการกรองสัญญาณจากปุ่มกดให้มีความเสถียรและไม่เกิดการสั่นไหวได้อย่างมีประสิทธิภาพ

ปัญหาที่ตามมาจากการใส่ RC Debounce นี้คือจะทำให้ D-FF ที่ใช้ในการควบคุมโหมดการทำงานของวงจรตั้งเวลา (Time Setting Circuit) ไม่สามารถทำงานได้อย่างถูกต้องและมีความเสถียร เนื่องจากเวลาไต่ขึ้นของสัญญาณจากปุ่มกดที่ผ่านวงจร Debounce จะมีความช้าและไม่คม ทำให้ D-FF ไม่สามารถทำงานได้อย่างถูกต้อง 

<p align="center">
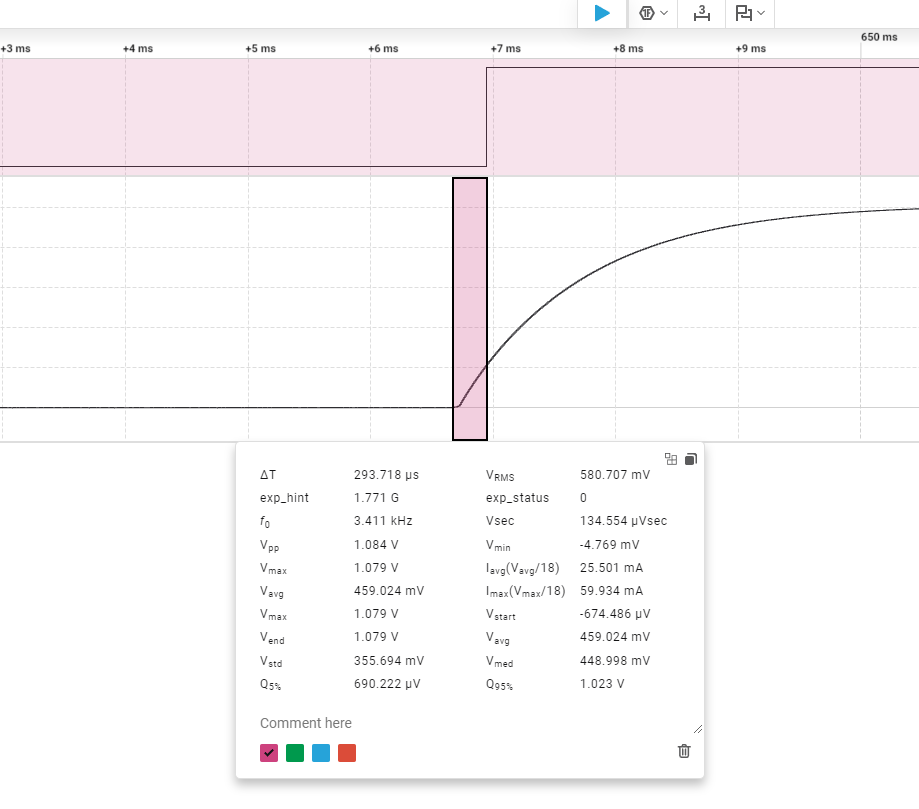
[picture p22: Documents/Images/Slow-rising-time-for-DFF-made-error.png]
Slow rising time for DFF made error

<br><b>รูปที่ 4</b> เวลาไต่ขึ้นของสัญญาณจากปุ่มกดที่ผ่านวงจร Debounce จะมีความช้าและไม่คม ทำให้ D-FF ไม่สามารถทำงานได้อย่างถูกต้อง
</p>

จากปัญหาในรูปที่ 4 เราจึงได้แก้ไขโดยการเพิ่มไอซี 74LS14 ซึ่งเป็น Schmitt Trigger Inverter เพื่อช่วยให้สัญญาณจากปุ่มที่ผ่านวงจร Debounce มีความคมมากพอที่จะทำให้ D-FF สามารถทำงานได้อย่างถูกต้องและมีความเสถียรมากขึ้น 

จากการทดลองใช้งานจริง พบว่าวงจร Debounce ที่มี Schmitt Trigger Inverter นี้สามารถกรองสัญญาณจากปุ่มกดได้อย่างมีประสิทธิภาพและทำให้ D-FF สามารถทำงานได้อย่างถูกต้องและมีความเสถียรมากขึ้น โดยไม่มีการเกิดการตั้งค่าเวลาที่ผิดเพี้ยนจากการกดปุ่มกดอีกต่อไปแล้ว สังเกตุได้จากการทดลองกด Switch ที่มีวงจร debounce ติดกัน 5 ครั้ง พบว่าในทุกจังหวะ มีเอาต์พุตออกมาจาก switch เพียงแค่ 5 ครั้งเท่านั้น แทนที่จะ มากถึง 11 ครั้งเหมือนในกรณีที่ไม่มีวงจร debounce ซึ่งแสดงให้เห็นว่าวงจร Debounce ที่มี Schmitt Trigger Inverter นี้สามารถกรองสัญญาณจากปุ่มกดได้อย่างมีประสิทธิภาพและทำให้ D-FF สามารถทำงานได้อย่างถูกต้องและมีความเสถียรมากขึ้น ดังรูปที่ 5 

<p align="center">
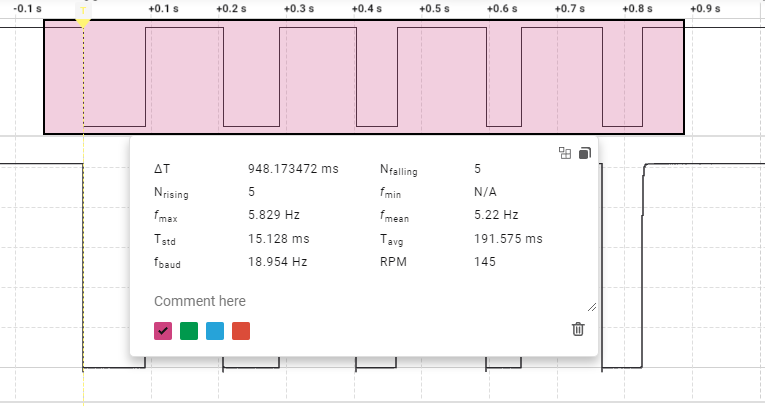
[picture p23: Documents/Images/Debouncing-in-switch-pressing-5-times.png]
Debouncing in Switch Pressing 5 Times

<br><b>รูปที่ 5</b> วงจร Debounce ที่มี Schmitt Trigger Inverter สามารถกรองสัญญาณจากปุ่มกดได้อย่างมีประสิทธิภาพและทำให้ D-FF สามารถทำงานได้อย่างถูกต้องและมีความเสถียรมากขึ้น
</p>

ความโชคดีประการหนึ่งที่เราเจอจากวงจรนี้ คือเราสามารถใช้เอาต์พุตจาก Schmitt Trigger Inverter นี้ไปควบคุมการทำงานของ D-FF ได้เลย โดยไม่ต้องเพิ่มวงจร Inverter เพิ่มเติมอีกวงหนึ่ง ซึ่งจะช่วยให้การออกแบบวงจรตั้งเวลา (Time Setting Circuit) มีความเรียบง่ายและซับซ้อนน้อยลง ซึ่งเอาต์พุตจาก D-FF จะถูกส่งไปยังวงจรควบคุม (Controller) เพื่อให้สามารถสลับโหมดการทำงานระหว่างโหมดนาฬิกาและโหมดตั้งเวลา 

เหตุผลที่เราเลือกใช้ D-FF ในการควบคุมโหมดการทำงานของวงจรตั้งเวลา (Time Setting Circuit) แทนสวิตช์เลือกแบบแมคานิกส์เพราะ D-FF เป็นไอซีที่มีความเสถียรและสามารถเก็บสถานะได้อย่างแม่นยำ เมื่อใช้ไปนาน ๆ สวิตช์เลือกแบบแมคานิกส์อาจจะเกิดการสึกหรอหรือเสียหาย ทำให้เกิดการสลับโหมดไปมาโดยไม่ตั้งใจ การใช้ D-FF สามารถช่วยให้เราเลือกโหมดทำงานแบบอิเล็กทรอนิกส์ นั่นหมายความว่าเราอาจจะใช้รีโมทคอนโทรลหรือสัญญาณจากไมโครคอนโทรลเลอร์ในการควบคุมโหมดการทำงานของวงจรตั้งเวลา (Time Setting Circuit) ได้ในอนาคต ซึ่งจะช่วยเพิ่มความสะดวกสบายและความยืดหยุ่นในการใช้งานได้มากขึ้นอีกด้วย

โหมดการทำงาน จะแสดงด้วย LED สีเขียวถ้า LED สีเขียวดับ หมายถึงวงจรอยู่ในโหมดนาฬิกา โดยจะรับ clock จาก NE555 แต่ถ้า LED สีเขียวติดอยู่ หมายถึงวงจรอยู่ในโหมดตั้งเวลา โดยจะรับ clock จากการกดปุ่มตั้งเวลาแทน ซึ่งจะทำให้ผู้ใช้งานสามารถตั้งค่าเวลาได้

### 2. ปุ่มกด (Push Button) เลือกตั้งเวลา (ในโหมด Time Setting)

ปุ่มกดอีก 3 ปุ่มที่เหลือ ใช้เพื่อกำหนดให้สามารถตั้งค่าเวลา (ชั่วโมง นาที วินาที) โดยปุ่มกดทั้งสามนี้ จะทำงานร่วมกับวงจรควบคุม (Controller) เพื่อส่งสัญญาณไปยังวงจรนับเวลา (Counter) ที่แยกจากกันโดยอิสระโดยไอซี 741LS57 (อธิบายในหัวข้อถัดไป) เพื่อให้สามารถตั้งค่าเวลาได้อย่างถูกต้องและง่ายดาย โดยปุ่มกดแต่ละปุ่มจะมีหน้าที่ดังนี้

ปุ่มกดทั้งสามนี้จะมีวงจร Debounce และ Schmitt Trigger Inverter เหมือนกับปุ่มกดเลือกโหมดการทำงาน ต่างกันตรงที่จะใมีการต่อตัวต้านทานแบบ pull-down เพื่อให้ได้เอาต์พุของ schmitt trigger inverter เป็น 0V เมื่อไม่มีการกดปุ่ม และจะได้เอาต์พุตเป็น 5V เมื่อมีการกดปุ่ม ซึ่งจะช่วยให้การส่งสัญญาณไปยังวงจรนับ (Counter) ทำให้มีการนับขึ้นตอนกดสวิตช์ไม่ใช่ตอนปล่อยสวิตช์เหมือนกับปุ่มกดเลือกโหมดการทำงาน ซึ่งจะช่วยให้การตั้งค่าเวลาเป็นไปตามความรู้สึกของผู้ใช้งานมากขึ้น  

#### การทำงานที่ออกแบบไว้

การทำงานที่คาดหวังของวงจรควบคุม เป็นไปตามตารางที่ 1

ตารางที่ 1 เงื่อนไขการทำงานของปุ่มกด

| อุปกรณ์ | โหมดตั้งเวลา | โหมดนาฬิกา |
| --- | --- | --- |
| LED สีเขียว | ติดเมื่ออยู่ในโหมดตั้งเวลา | ดับเมื่ออยู่ในโหมดนาฬิกา |
| ปุ่มกดที่หนึ่ง | ส่งผ่าน  74LS157 ไปยัง counter ชั่วโมง | ไม่ส่งผลต่อการทำงาน |
| ปุ่มกดที่สอง | ส่งผ่าน  74LS157 ไปยัง counter นาที | ไม่ส่งผลต่อการทำงาน |
| ปุ่มกดที่สาม | ส่งผ่าน  74LS157 ไปยัง counter วินาที  | ไม่ส่งผลต่อการทำงาน |

### 3.  ไอซี 74LS157 Multiplexer

ไอซี 74LS157 เป็น Multiplexer ที่มี 2 ช่องสัญญาณเข้า (2-to-1 Multiplexer) จำนวน 4 ชุด  ทำให้เราสามารถใช้ตัดต่อเส้นทางของสัญญาณ Clock ได้อย่างง่ายดาย โดยการใช้เอาต์พุตจาก D-FF ที่ใช้ในการควบคุมโหมดการทำงานของวงจรตั้งเวลา (Time Setting Circuit) มาเป็นสัญญาณควบคุมการทำงานของไอซี 74LS157

``` mermaid
%%{init: {'theme':'base', 'flowchart': {'padding': 20, 'nodeSpacing': 40, 'rankSpacing': 40}, 'themeVariables': {'fontSize':'13px', 'fontFamily':'Arial'}}}%%

flowchart LR
    IN1 --> MUX1["74LS157<br> 1/4"]
    CTRL --> MUX1["74LS157<br> 1/4"]
    IN2 --> MUX1["74LS157<br> 1/4"]
    MUX1 --> OUT1
```
<p align="center">
<b> รูปที่ 6</b> ไอซี 74LS157 เป็น Multiplexer ที่มี 2 ช่องสัญญาณเข้า (2-to-1 Multiplexer) จำนวน 4 ชุด
</p>

การออกแบบให้ไอซี 74LS157 ทำงานในวงจรจะเป็นไปตามตารางที่ 2 ซึ่งจะช่วยให้เราสามารถสลับเส้นทางของสัญญาณ Clock ได้อย่างง่ายดายและมีประสิทธิภาพ โดยไม่ต้องไปแก้ไขวงจรนับเวลา (Counter) หรือส่วนแสดงผล (Display) แต่อย่างใด

จากตารางที่ 1 เราสามารถนำมาออกแบบวงจรควบคุม (Controller) ได้ดังนี้

<b>ตารางที่ 2</b> เงื่อนไขการทำงานของ 74157

| MUX 2:1 <br>(ใน 74157) | โหมดตั้งเวลา <br>(LED เขียว ติด) | โหมดนาฬิกา <br>(LED เขียว ดับ) |
| :---: | :---: | :---: |
| ชุดที่ 1 | [NE555] ---> [SEC counter] |  [SEC SW] ---> [SEC counter] |
| ชุดที่ 2 | [SEC counter overflow] ---> [MIN counter]  |  [MIN SW] ---> [MIN counter] |
| ชุดที่ 3 | [MIN counter overflow] ---> [HOUR counter] | [HOUR SW] ---> [HOUR counter]  |

#### การทำงานในโหมดนาฬิกา (LED เขียว ดับ)

``` mermaid
%%{init: {'theme':'base', 'flowchart': {'padding': 20, 'nodeSpacing': 40, 'rankSpacing': 40}, 'themeVariables': {'fontSize':'13px', 'fontFamily':'Arial'}}}%%

flowchart TB
    NE555["1 Hz Clock"] --> |1 sec|MUX1["74157<br> ชุดที่ 1"]
    MUX1  --> |1 sec| SEC["74LS390<br>SEC Counter"]
    SEC --> |เมื่อ SEC นับครบ 60| MUX2["74157<br> ชุดที่ 2"]
    MUX2 --> |1 min| MIN["74LS390<br>MIN Counter"]
    MIN --> |เมื่อ MIN นับครบ 60| MUX3["74157<br> ชุดที่ 3"]
    MUX3 --> |1 hr| HOUR["74LS390<br>HOUR Counter"]    
```
<p align="center">
<b> รูปที่ 7</b> เส้นทางของสัญญาณ Clock ในโหมดนาฬิกา (LED เขียว ดับ)
</p>

#### การทำงานในโหมดตั้งเวลา (LED เขียว ติด)

``` mermaid 
%%{init: {'theme':'base', 'flowchart': {'padding': 20, 'nodeSpacing': 40, 'rankSpacing': 40}, 'themeVariables': {'fontSize':'13px', 'fontFamily':'Arial'}}}%%

flowchart TB
    SECPB["ปุ่มกดวินาที"] --> |ความเร็วตามที่กดปุ่ม|MUX1["74157<br> ชุดที่ 1"] --> |ความเร็วตามที่กดปุ่ม| SEC["74LS390<br>SEC Counter"]
    MINPB["ปุ่มกดนาที"] --> |ความเร็วตามที่กดปุ่ม|MUX2["74157<br> ชุดที่ 2"] --> |ความเร็วตามที่กดปุ่ม| MIN["74LS390<br>MIN Counter"]
    HOURPB["ปุ่มกดชั่วโมง"] --> |ความเร็วตามที่กดปุ่ม|MUX3["74157<br> ชุดที่ 3"] --> |ความเร็วตามที่กดปุ่ม| HOUR["74LS390<br>HOUR Counter"]
```
<p align="center">
<b> รูปที่ 8</b> เส้นทางของสัญญาณ Clock ในโหมดตั้งเวลา (LED เขียว ติด)
</p>

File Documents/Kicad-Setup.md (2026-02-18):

## Download and install Kicad

1. ดาวน์โหลด Kicad ได้จาก https://www.kicad.org/download/
2. ติดตั้งตามขั้นตอนปกติ
3. เปิดไฟล์ Digital_Clock_6_Digits.kicad_pro จากโฟลเดอร์ circuit  ใน repo นี้

<p align="center">
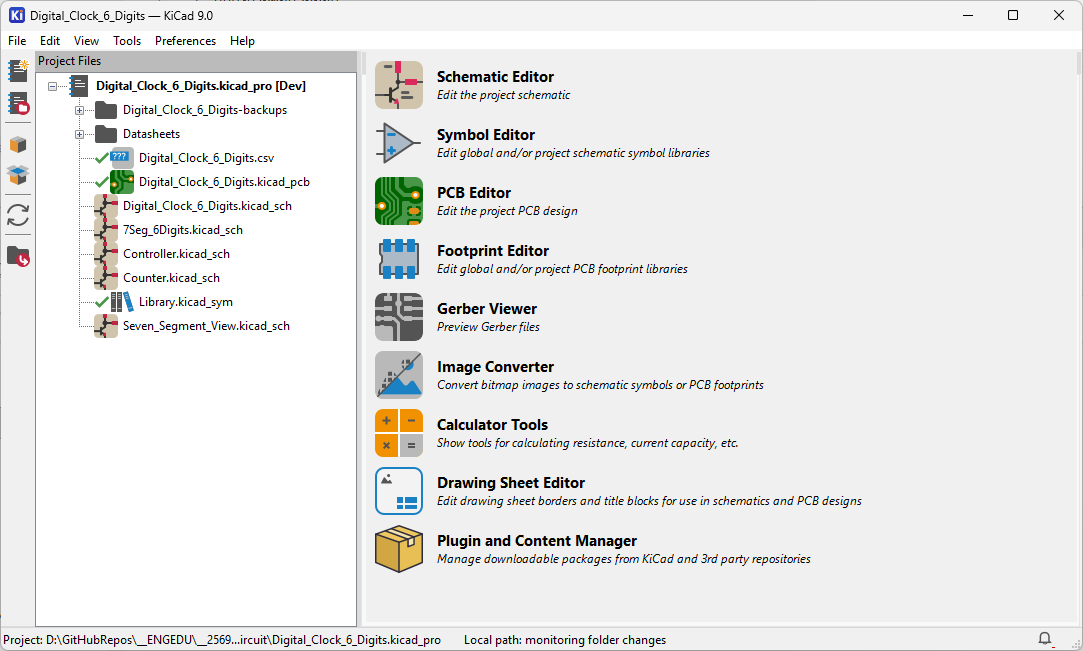
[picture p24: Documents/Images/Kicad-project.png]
Kicad Project

</p>

 4. คลิกที่ไอคอน Schematic Editor จะเป็นการเปิดไฟล์ Digital_Clock_6_Digits.kicad_sch ซึ่งเป็น Schematic หลักที่เชื่อมโยงส่วนย่อยทั้งหมดในโปรเจคนี้

<p align="center">
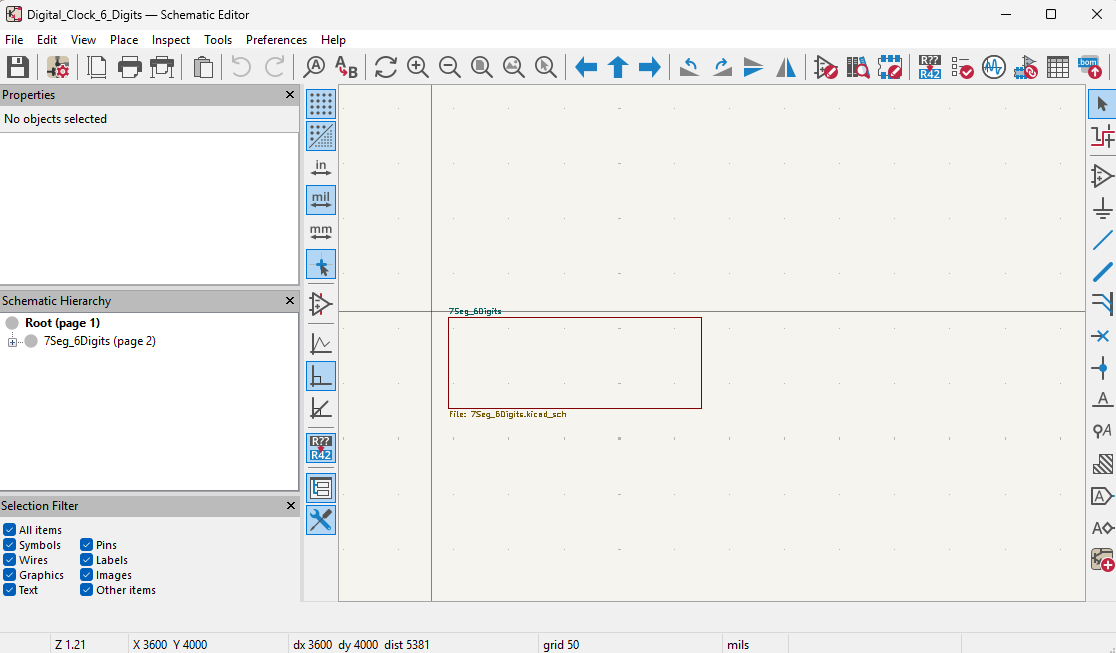
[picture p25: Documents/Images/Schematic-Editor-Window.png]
Schematic Editor Window

</p>

 5. คลิกเมนู View -> Panels -> Hierarchy Navigator หรือกด `Ctrl+H`   เพื่อเปิดแผง Hierarchy Navigator ที่ช่วยให้เราดูโครงสร้างของ Schematic ได้ง่ายขึ้น
  
<p align="center">
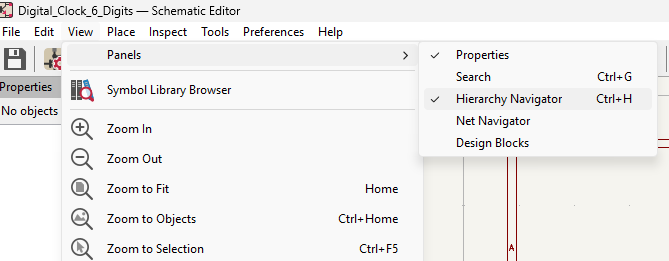
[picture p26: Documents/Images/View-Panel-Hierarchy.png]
View Panel Hierarchy

</p>

6. จะเห็นแผง Hierarchy Navigator ที่แสดงโครงสร้างของ Schematic ในโปรเจคนี้ ซึ่งมีการแบ่งเป็นส่วนย่อย ๆ เพื่อความสะดวกในการออกแบบและแก้ไข ให้คลี่ออกมา แล้วคลิกที่ `Seven_Segment_View` เพื่อดูการเชื่อมต่อของ 7-Segment Display

<p align="center">
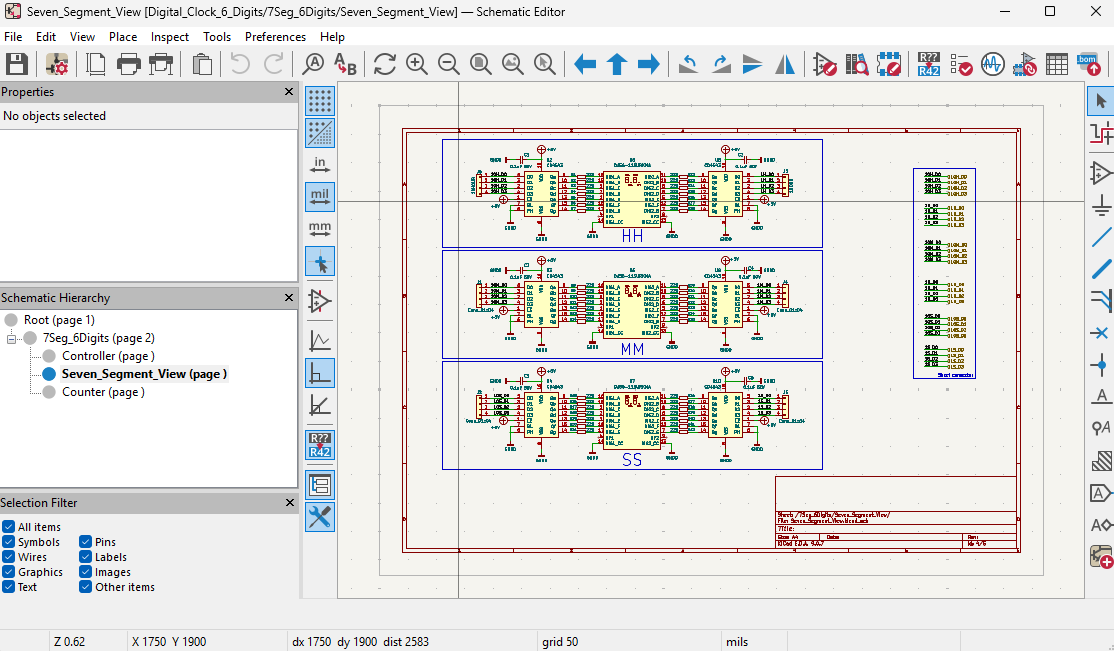
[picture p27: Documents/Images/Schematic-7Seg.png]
Schematic 7-Segment

</p>

นักศึกษาสามารถคลิกที่ส่วนอื่น ๆ ใน Hierarchy Navigator เพื่อดูรายละเอียดของแต่ละส่วนได้เช่นกัน เช่น Controller หรือ Counter ซึ่งจะช่วยให้เข้าใจการทำงานของวงจรได้ดีขึ้นครับ

**ในโปรเจคนี้เราใช้ KiCad ในการดูวงจรที่จะประกอบเท่านั้นนะครับ ไม่ได้ใช้ในการออกแบบวงจรใหม่** 

ถ้าอยากออกแบบวงจรใหม่ก็สามารถใช้ KiCad นี้ได้เลยครับ  
และถ้าต้องการเรียนรู้การใช้งาน KiCad เพิ่มเติมก็สามารถดูได้จากคู่มือออนไลน์ของ KiCad ได้เลยครับ https://docs.kicad.org/ หรือถ้ามีคำถามเพิ่มเติมก็สามารถเปิด issue มาได้เลยนะครับ

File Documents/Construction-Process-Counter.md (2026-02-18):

## การประกอบวงจรนับเวลา (Counter)

ในส่วนนี้เราจะมาดูขั้นตอนการประกอบวงจรนับเวลา (Counter) ซึ่งเป็นส่วนที่สำคัญมาก ๆ ในโครงงานนี้ เพราะเป็นส่วนที่ทำหน้าที่นับและจัดเก็บค่าเวลา (ชั่วโมง นาที วินาที) ในรูปแบบ BCD ซึ่งจะถูกส่งไปยังส่วนแสดงผล (View) เพื่อแสดงผลออกมาให้เราเห็น

***ถ้าหากมีข้อสงสัยในการทำงานของวงจรนับเวลา (Counter) สามารถดูได้จากเอกสารนี้  [Counter Design](Counter-Design.md) ซึ่งจะอธิบายการทำงานของวงจรนับเวลาอย่างละเอียด และมีตัวอย่างการคำนวณและการออกแบบวงจรนับเวลาที่ใช้ในโครงงานนี้ด้วย***

<p align="center">
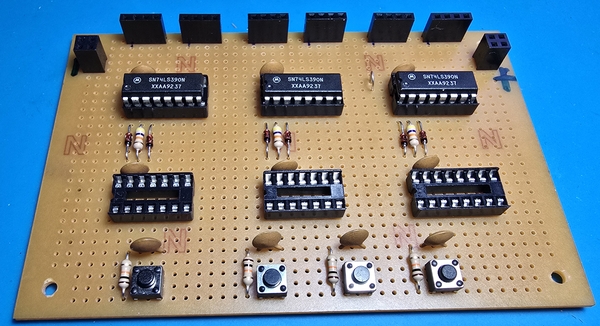
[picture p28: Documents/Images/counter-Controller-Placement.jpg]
Counter Controller Placement

</p>

นักศึกษาสามารถใช้วงจรในหน้าที่ 3 ของไฟล์ใน Kicad ที่ชื่อว่า "Counter" ซึ่งเป็นวงจรนับเวลาที่ออกแบบมาแล้วในรูปแบบ BCD โดยมีการใช้ไอซี 74LS90 ในการนับและจัดเก็บค่าเวลา และมีการเชื่อมต่อกับส่วนแสดงผล (Display) ผ่านทางขั้วต่อ (Connector) เพื่อให้สามารถส่งสัญญาณไปยังส่วนแสดงผลได้อย่างถูกต้องและง่ายดาย

ถ้ามีข้อสงสัยในการประกอบวงจรนับเวลา (Counter) สามารถเปิด issue ถามมาใน github repo ได้เลยครับ

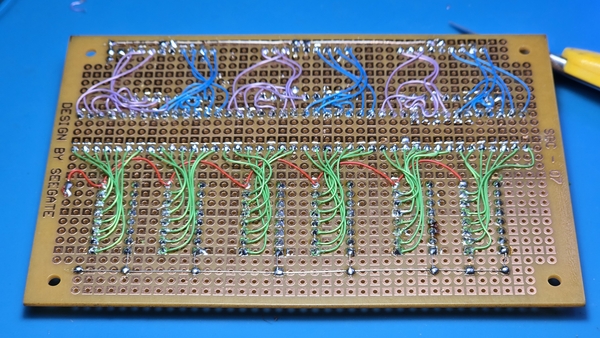
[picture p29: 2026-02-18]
Documents/Images/wire-wrapping-soldering-display-board.jpg

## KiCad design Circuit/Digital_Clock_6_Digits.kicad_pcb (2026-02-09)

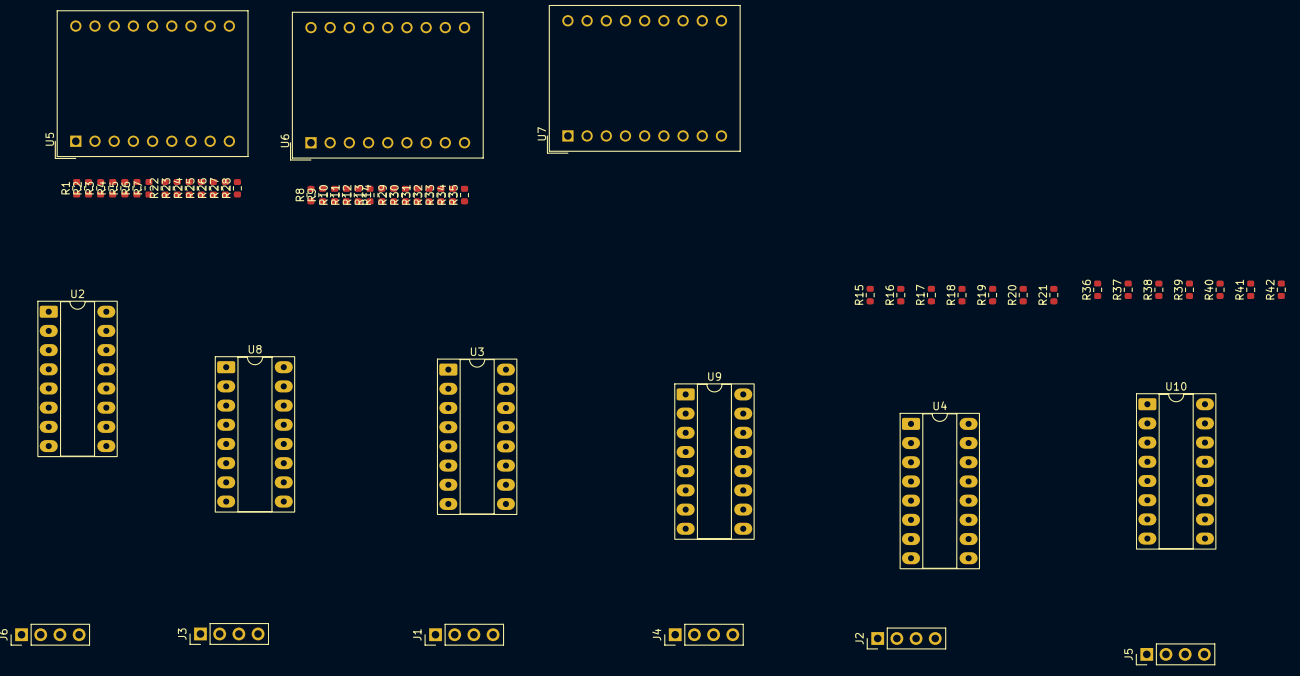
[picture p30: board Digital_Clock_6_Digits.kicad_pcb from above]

Board: 2 copper layers, 57 parts (0 on the bottom side), 110 nets, no tracks yet.

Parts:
J1, J2, J3, J4, J5, J6: Conn_01x04; PinHeader_1x04_P2.54mm_Vertical
R1, R2, R3, R4, R5, R6, R7, R8, R9, R10, R11, R12, R13, R14, R15, R16, R17, R18, R19, R20, R21, R22, R23, R24, R25, R26, R27, R28, R29, R30, R31, R32, R33, R34, R35, R36, R37, R38, R39, R40, R41, R42: 220; R_0603_1608Metric
U2, U3, U4, U8, U9, U10: 4543; DIP-16_W7.62mm_Socket_LongPads
U5, U6, U7: DA56-11SURKWA; DA56-11CGKWA

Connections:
+5V: U2.1 (~LE), U2.16 (VDD), U3.1 (~LE), U3.16 (VDD), U4.1 (~LE), U4.16 (VDD), U8.1 (~LE), U8.16 (VDD), U9.1 (~LE), U9.16 (VDD), U10.1 (~LE), U10.16 (VDD)
/7Seg_6Digits/Seven_Segment_View/1H_D0: J3.1, U8.5 (D0)
/7Seg_6Digits/Seven_Segment_View/1H_D1: J3.2, U8.3 (D1)
/7Seg_6Digits/Seven_Segment_View/1H_D2: J3.3, U8.2 (D2)
/7Seg_6Digits/Seven_Segment_View/1H_D3: J3.4, U8.4 (D3)
/7Seg_6Digits/Seven_Segment_View/1M_D0: J4.1, U9.5 (D0)
/7Seg_6Digits/Seven_Segment_View/1M_D1: J4.2, U9.3 (D1)
/7Seg_6Digits/Seven_Segment_View/1M_D2: J4.3, U9.2 (D2)
/7Seg_6Digits/Seven_Segment_View/1M_D3: J4.4, U9.4 (D3)
/7Seg_6Digits/Seven_Segment_View/1S_D0: J5.1, U10.5 (D0)
/7Seg_6Digits/Seven_Segment_View/1S_D1: J5.2, U10.3 (D1)
/7Seg_6Digits/Seven_Segment_View/1S_D2: J5.3, U10.2 (D2)
/7Seg_6Digits/Seven_Segment_View/1S_D3: J5.4, U10.4 (D3)
/7Seg_6Digits/Seven_Segment_View/10H_D0: J6.1, U2.5 (D0)
/7Seg_6Digits/Seven_Segment_View/10H_D1: J6.2, U2.3 (D1)
/7Seg_6Digits/Seven_Segment_View/10H_D2: J6.3, U2.2 (D2)
/7Seg_6Digits/Seven_Segment_View/10H_D3: J6.4, U2.4 (D3)
/7Seg_6Digits/Seven_Segment_View/10M_D0: J1.1, U3.5 (D0)
/7Seg_6Digits/Seven_Segment_View/10M_D1: J1.2, U3.3 (D1)
/7Seg_6Digits/Seven_Segment_View/10M_D2: J1.3, U3.2 (D2)
/7Seg_6Digits/Seven_Segment_View/10M_D3: J1.4, U3.4 (D3)
/7Seg_6Digits/Seven_Segment_View/10S_D0: J2.1, U4.5 (D0)
/7Seg_6Digits/Seven_Segment_View/10S_D1: J2.2, U4.3 (D1)
/7Seg_6Digits/Seven_Segment_View/10S_D2: J2.3, U4.2 (D2)
/7Seg_6Digits/Seven_Segment_View/10S_D3: J2.4, U4.4 (D3)
GND: U2.6 (PH), U2.7 (BL), U2.8 (VSS), U3.6 (PH), U3.7 (BL), U3.8 (VSS), U4.6 (PH), U4.7 (BL), U4.8 (VSS), U5.13 (DIG2_CC), U5.14 (DIG1_CC), U6.13 (DIG2_CC), U6.14 (DIG1_CC), U7.13 (DIG2_CC), U7.14 (DIG1_CC), U8.6 (PH), U8.7 (BL), U8.8 (VSS), U9.6 (PH), U9.7 (BL), U9.8 (VSS), U10.6 (PH), U10.7 (BL), U10.8 (VSS)
unnamed: R1.1, U2.9 (Qa)
unnamed: R2.1, U2.10 (Qb)
unnamed: R3.1, U2.11 (Qc)
unnamed: R4.1, U2.12 (Qd)
unnamed: R5.1, U2.13 (Qe)
unnamed: R6.1, U2.15 (Qf)
unnamed: R7.1, U2.14 (Qg)
unnamed: R8.1, U3.9 (Qa)
unnamed: R9.1, U3.10 (Qb)
unnamed: R10.1, U3.11 (Qc)
unnamed: R11.1, U3.12 (Qd)
unnamed: R12.1, U3.13 (Qe)
unnamed: R13.1, U3.15 (Qf)
unnamed: R14.1, U3.14 (Qg)
unnamed: R15.1, U4.9 (Qa)
unnamed: R16.1, U4.10 (Qb)
unnamed: R17.1, U4.11 (Qc)
unnamed: R18.1, U4.12 (Qd)
unnamed: R19.1, U4.13 (Qe)
unnamed: R20.1, U4.15 (Qf)
unnamed: R21.1, U4.14 (Qg)
unnamed: R1.2, U5.16 (DIG1_A)
unnamed: R2.2, U5.15 (DIG1_B)
unnamed: R3.2, U5.3 (DIG1_C)
unnamed: R4.2, U5.2 (DIG1_D)
unnamed: R5.2, U5.1 (DIG1_E)
unnamed: R6.2, U5.18 (DIG1_F)
unnamed: R7.2, U5.17 (DIG1_G)
unnamed: R22.2, U5.11 (DIG2_A)
unnamed: R23.2, U5.10 (DIG2_B)
unnamed: R24.2, U5.8 (DIG2_C)
unnamed: R25.2, U5.6 (DIG2_D)
unnamed: R26.2, U5.5 (DIG2_E)
unnamed: R27.2, U5.12 (DIG2_F)
unnamed: R28.2, U5.7 (DIG2_G)
unnamed: R8.2, U6.16 (DIG1_A)
unnamed: R9.2, U6.15 (DIG1_B)
unnamed: R10.2, U6.3 (DIG1_C)
unnamed: R11.2, U6.2 (DIG1_D)
unnamed: R12.2, U6.1 (DIG1_E)
unnamed: R13.2, U6.18 (DIG1_F)
unnamed: R14.2, U6.17 (DIG1_G)
unnamed: R29.2, U6.11 (DIG2_A)
unnamed: R30.2, U6.10 (DIG2_B)
unnamed: R31.2, U6.8 (DIG2_C)
unnamed: R32.2, U6.6 (DIG2_D)
unnamed: R33.2, U6.5 (DIG2_E)
unnamed: R34.2, U6.12 (DIG2_F)
unnamed: R35.2, U6.7 (DIG2_G)
unnamed: R15.2, U7.16 (DIG1_A)
unnamed: R16.2, U7.15 (DIG1_B)
unnamed: R17.2, U7.3 (DIG1_C)
unnamed: R18.2, U7.2 (DIG1_D)
unnamed: R19.2, U7.1 (DIG1_E)
unnamed: R20.2, U7.18 (DIG1_F)
unnamed: R21.2, U7.17 (DIG1_G)
unnamed: R36.2, U7.11 (DIG2_A)
unnamed: R37.2, U7.10 (DIG2_B)
unnamed: R38.2, U7.8 (DIG2_C)
unnamed: R39.2, U7.6 (DIG2_D)
unnamed: R40.2, U7.5 (DIG2_E)
unnamed: R41.2, U7.12 (DIG2_F)
unnamed: R42.2, U7.7 (DIG2_G)
unnamed: R22.1, U8.9 (Qa)
unnamed: R23.1, U8.10 (Qb)
unnamed: R24.1, U8.11 (Qc)
unnamed: R25.1, U8.12 (Qd)
unnamed: R26.1, U8.13 (Qe)
unnamed: R27.1, U8.15 (Qf)
unnamed: R28.1, U8.14 (Qg)
unnamed: R29.1, U9.9 (Qa)
unnamed: R30.1, U9.10 (Qb)
unnamed: R31.1, U9.11 (Qc)
unnamed: R32.1, U9.12 (Qd)
unnamed: R33.1, U9.13 (Qe)
unnamed: R34.1, U9.15 (Qf)
unnamed: R35.1, U9.14 (Qg)
unnamed: R36.1, U10.9 (Qa)
unnamed: R37.1, U10.10 (Qb)
unnamed: R38.1, U10.11 (Qc)
unnamed: R39.1, U10.12 (Qd)
unnamed: R40.1, U10.13 (Qe)
unnamed: R41.1, U10.15 (Qf)
unnamed: R42.1, U10.14 (Qg)

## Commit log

2026-01-31 Add KiCad project files for 6-digit clock
    Add initial KiCad project for Digital_Clock_6_Digits: schematic (.kicad_sch), PCB (.kicad_pcb) and project file (.kicad_pro). Also add .gitignore to ignore KiCad lock files (*.lck) and .vscode. Files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
    [Digital_Clock_6_Digits.kicad_pcb, Digital_Clock_6_Digits.kicad_sch]
2026-01-31 Add backup files and create project settings for Digital Clock 6 Digits
    - Added a backup zip file containing project files and settings.
    - Created a new KiCad project settings file (Digital_Clock_6_Digits.kicad_prl) with configuration for board visibility, selection filters, and net inspector panel settings.
    [7Seg_6Digits.kicad_sch, Digital_Clock_6_Digits.kicad_sch]
2026-02-03 Refactor code structure for improved readability and maintainability
    add Top lecvel and 6 Digits view
    [7Seg_6Digits.kicad_sch, Controller.kicad_sch, Counter.kicad_sch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]
2026-02-04 Add 74LS192 counter and project links
    Add a 74LS192 symbol definition and instance to Counter.kicad_sch (includes pins, properties and a U1 instance). Update Digital_Clock_6_Digits.kicad_pro to register Controller, Seven_Segment_View and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
    [Counter.kicad_sch, Seven_Segment_View.kicad_sch]
2026-02-09 Add initial component list for Digital Clock project
    - Created a new CSV file 'Digital_Clock_6_Digits.csv' to define components.
    - Included details such as designators, footprints, quantities, and designations for resistors, connectors, and ICs.
    [Digital_Clock_6_Digits.csv, Digital_Clock_6_Digits.kicad_pcb, Seven_Segment_View.kicad_sch]
2026-02-16 Reorganize circuit files into Circuit/ directory
    Move PCB, CSV, datasheet and project files into a new Circuit/ subdirectory, add multiple backup ZIPs under Circuit/Digital_Clock_6_Digits-backups, and add symbol library files (Library.bak, Library.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
    [7Seg_6Digits.kicad_sch, Controller.kicad_sch, Counter.kicad_sch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]
2026-02-17 Add Circuit backup path to .gitignore
    Add /Circuit/Digital_Clock_6_Digits-backups to .gitignore to exclude the Circuit project's backup directory and prevent accidental commits of backup files.
2026-02-18 Ignore .obsidian; update workspace and README
    Add .obsidian to .gitignore, adjust Obsidian workspace (lastOpenFiles ordering and added entries), and significantly revise Readme.md. The README changes remove the "Optional" label from Time Setting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
2026-02-18 Add Bill of Materials and Datasheets documentation; remove obsolete Datasheet file
2026-02-18 Enhance Kicad setup documentation with detailed instructions for Schematic Editor and Hierarchy Navigator
2026-02-18 Add images for soldering examples in Construction Process documentation
2026-02-18 Remove redundant reference to the Construction Process document in the Counter assembly instructions
2026-02-18 Fix link to Counter Design document in assembly instructions
2026-03-04 chore: clean up code structure and remove redundant changes
    [7Seg_6Digits.kicad_sch, Controller.kicad_sch, Counter.kicad_sch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]
